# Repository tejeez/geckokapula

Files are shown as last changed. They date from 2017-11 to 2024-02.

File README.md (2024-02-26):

# Gekkokapula
Silicon Labs EFR32 transceivers give access to filtered IQ samples on receive,
so it's possible to make a multimode handheld transceiver using them.

## Features
* Waterfall display (12 kHz wide)
* Receives FM, AM, USB, LSB, CW
* Transmits FM, CW, [USB*](#ssb-transmit), [LSB*](#ssb-transmit)
* Minimalistic user interface with a single knob

## Construction
There are two major versions of the hardware.
The first version is built around a
[BRD4151](https://www.silabs.com/documents/public/reference-manuals/brd4151a-rm.pdf)
radio module and only works in the 2.3-2.9 GHz band.
See [hardware\_v1/](hardware_v1/README.md) for details.

The second version is built on a custom PCB and uses a dual band EFR32 chip.
See [hardware_v2/pcb/](hardware_v2/pcb/) for a KiCad schematic and PCB design.
Construction is documented in [hardware_v2 README file](hardware_v2/README.md).

There is also a [tutorial for flashing firmware](firmware/flashing.md).

## Frequency range for the dual band model
The second version was initially designed for the 70 cm (432 MHz)
and 13 cm (2.3 GHz) amateur radio bands. Later it was found that
the EFR32 can be made to tuner over a much broader range.
Matching circuits of sub-GHz path in current hardware are optimized
for 70 cm but work reasonably well for lower frequencies as well.
Modification for the 23 cm band should be possible but has not
been attempted yet.

Tuning range has some gaps but covers the following frequencies:
* 13.2 - 725 MHz
* 766.7 - 966.6 MHz
* 1.15 - 1.45 GHz
* 2.3 - 2.9 GHz

## SSB transmit

\* SSB is transmitted as a constant envelope signal by only modulating
the frequency of a synthesizer. Amplitude variations are discarded and
the synthesizer is made to approximately track the phase of an SSB
modulated signal. This results is somewhat distorted audio and some
splatter to neighboring channels, but it sounds surprisingly
intelligible and has even received reports of good sound quality.
During quiet moments, some carrier is added in order to have
something to transmit.

Having a slightly dirty spectrum, this SSB transmitting trick
may not be suitable for high transmit power on a crowded bands,
but is probably acceptable for VHF/UHF contacts at low transmit power.

## Licensing

The firmware is released under the [MIT license](firmware/LICENSE).
It depends on the Gecko SDK from Silicon Labs,
mostly licensed under the Zlib license.

I haven't decided on licensing of the hardware design yet.

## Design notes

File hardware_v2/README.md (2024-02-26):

# Hardware version 2.2

## Overview

The Gekkokapula kit currently includes:
* Gekkokapula PCB v2.2
* Display module
* Pin header for display module
* 2 U.FL-SMA cables

To build a complete radio, you will additionally need:
* Enclosure
* Speaker
* Quadrature encoder (may be added to kit in future)
* Electret microphone (may be added to kit in future)
* 1S Li-Ion (or 3S NiMH) battery
* PTT button (optional)
* Volume potentiometer (optional)
* Power switch (optional)
* Serial Wire Debug adapter (to update firmware)

Most of these parts are connected to header J1 on the Gekkokapula PCB.
Schematic diagram of wiring between header J1 and other parts:

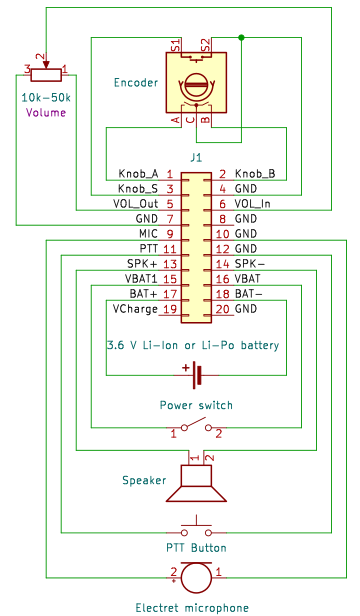
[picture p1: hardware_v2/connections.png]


It is a good idea to connect the battery last after connecting
everything else. This reduces the risk of accidental short circuits
during construction.

## Detailed information

### Gekkokapula board
The Gekkokapula PCB contains most of the electronics.
All SMD components are already placed on the board, so
you only need to hand solder some through hole pin headers.
All bigger and more "mechanical" parts are wired to these
pin headers. This lets you choose any enclosure
you like and arrange all the knobs, buttons and connectors
the way you like.

### Display
Solder 8-pin female header to J9 on Gekkokapula board
and plug display module into the header.

The display is a
[128x160 RGB TFT module with an 8-pin header](https://www.ebay.com/itm/403774302965).

These display modules also include an SD card slot
but it is not used for anything in Gekkokapula.
The 4-pin SD card header J10, however, can be placed and used for
additional mechanical support and ground pins.

### Encoder
The most important part of the user interface is a quadrature
encoder with a push button.
Connect one as shown in the wiring diagram above.

### Speaker
Connect a speaker between SPK+ and SPK- pins
(pins 13 and 14 on header J1).
Almost any speaker should work.
A 4 Ω or 8 Ω speaker with a power handling of at least 1 W
is recommended.

Keep in mind that most speakers need an enclosure to work properly.
A small speaker without an enclosure may sound too quiet.

### Microphone
Connect an electret microphone capsule between MIC and GND
(pins 9 and 10 on header J1).
Most electret microphones should work here.

### Battery
The board includes a protection circuit and a charger for a single
cell Li-Ion or Li-Po battery with a nominal voltage of 3.6 or 3.7 V.
For example, a flat cellphone battery or a 18650 cell can be used.

Connect battery between BAT+ and BAT- pins
(pins 17 and 18 on header J1). Note that battery minus is not
directly connected to ground (because of the protection circuit).

Although designed for Lithium batteries, the circuit also works
with 3 NiMH cells in series, since their voltages are
[close enough](https://www.ti.com/lit/an/slyt468/slyt468.pdf)
to 1S Li-Ion.

### Charging
The battery charger works with any supply voltage from 4 V to 9 V
between VCharge pin and GND (pins 19 and 20 on header J1).

5 V from a USB port or a cellphone charger works fine.

### RF connections
All RF connectors on the board are U.FL. Use pigtail cables
to adapt them to your favourite RF connectors.

13 cm band has its own connector, J3. It is used for
receiving and transmitting in the 2300-2900 MHz range.
All lower frequency bands (13 MHz to 1.45 GHz) use the
connector J5.

J4 is not connected by default but the board can be
[modified to make it an RX connector](#separate-connectors-for-rx-and-tx).

J6 (CLKOUT) is currently unused but may be used in future as a reference
frequency output for transverters.

## Optional parts

### PTT button
A PTT button is optional since transmitting can be also started
from the "menu" using the encoder.

If you prefer to have a dedicated button for PTT, connect one
between PTT and GND (pins 11 and 12 on header J1).

### Power switch
A power switch is optional since there is software and hardware
support for a sleep mode which reduces current consumption
to a few µA.

If you prefer to have a "real" power switch, connect a toggle
switch between PWSW pins (pins 15 and 16 on header J1).

If a switch is not used, connect pins 15 and 16 directly together.

### Volume potentiometer
A volume potentiometer is optional since volume can be also
adjusted from the "menu" using the encoder.

If you prefer to have a dedicated knob for volume, connect
a potentiometer between pins 5, 6 and 7 on header J1
as illustrated on the silkscreen.
Resistance of the potentiometer should be something from
10 kΩ to 50 kΩ.

If a potentiometer is not connected, connect pins 5 and 6
together. Volume can be also reduced by adding a fixed
series resistor or a voltage divider here.

## Bugs
PCB v2.1 has its RF switch control lines swapped.
This can be fixed by moving series resistors
R76 and R77 to cross the lines.
This has been fixed in version 2.2.

Sometimes the board does not power up after battery has been
connected. Seems like the battery protection chip ends up in
some state where it disconnects the battery. If this happens,
try momentarily shorting GND and BAT- together to bypass the
protection circuit. Usually it starts working and keeps working
as long as battery is kept connected.

Silkscreen marking of one expansion header pin in wrong in
both v2.1 and v2.2: pin 2 of J2 is marked as GND but is
actually connected to VBAT.

## Advanced use and modifications

### Updating firmware and debugging
The EFR32 chip on the board is flashed through
Serial Wire Debug (SWD). The board has a 10-pin header with
[Cortex Debug standard pinout](https://documentation-service.arm.com/static/5fce6c49e167456a35b36af1)
but using 2.54 mm pitch instead of the standard 1.27 mm pitch
(to make it easier to solder wires or connectors to it).

GND, SWCLK and SWDIO pins are required and shall be connected to
corresponding pins on your SWD adapter.

The VDD pin is an output meant for SWD adapters with a reference
voltage input (used for level shifters or target detection).
If your SWD adapter does not have a reference voltage input,
leave the VDD pin unconnected. Using this VDD pin to supply power
to the Gekkokapula board is not recommended.

If your SWD adapter has a 5 V output pin, it can be used to supply
power to the board by connecting 5 V to pin 16 on J1
(power switch pin).
If you have a battery connected, you can also connect 5 V
to pin 19 on J1 (VCharge) to charge the battery.

Any SWD adapter supported by OpenOCD should work but may need
additional configuration for OpenOCD.
I can try to add configuration for more adapters
if you can give me an adapter to test with.

See [flashing tutorial](../firmware/flashing.md) for details
on installation and use of flashing software.

### Using without battery
If you want to directly use an external power supply and bypass
battery protection and charging circuits, connect the supply
between power switch VBAT pin (pin 16 on J1) and ground
(such as pin 20 on J1).

The circuit can handle supply voltages from 3 V to 6 V.
Keep in mind that a higher voltage will result in higher power
dissipation in 3.3 V regulator and audio amplifier chips.
Recommended range is between 3.5 V and 5.0 V to keep voltage
regulator working and to keep its dissipation reasonable.

### Headphone connector
Output of the audio power amplifier is bridged, so neither end of
the speaker is connected to ground.

If you want to add a headphone jack, it may be more convenient to
connect one end of headphones to ground, particularly if you use
a 4-pin headset connector with a microphone pin. This can be done
but an additional DC blocking capacitor is needed.
Series resistors are also recommended to protect the audio amplifier
from short circuits.

TODO: diagram showing additional circuitry for a headphone jack

### Use on bands other than 13 cm and 70 cm
The board includes a low-pass filter (LPF) for the 70 cm band.
This is needed to suppress transmitter harmonics and receiver
harmonic mixing products.
RF matching circuits are also optimized for 70 cm but will
work on other bands with somewhat reduced transmit power
and receive sensitivity.

For use on other bands, the LPF should be bypassed
(by moving C82 and R78) and an external LPF should be
connected between J5 and an antenna.
Receiving lower bands without modification or external
filtering is possible but the receiver is prone to harmonic
mixing if a proper LPF is not used. This means you may hear
spurious responses from higher frequencies, such as
FM broadcast signals when trying to listen to HF,
or 70cm band signals when trying to listen to 2m.

### Separate connectors for RX and TX
J4 can be used as a separate receiving connector for frequencies
below 1.45 GHz. This can be useful with an external power amplifier,
low noise amplifier or a transverter.
To use J4, move capacitor C74 to connect receiving chain to J4
through TP5 (and to disconnect it from the RX/TX switch).

On 2300-2900 MHz, J3 is always used for both TX and RX.
Separate connectors for 13 cm are not available.

### Changing charging current
Charge current is limited to approximately 400 mA.
If you want to change the current limit, check the
[data sheet of the charger chip](https://datasheetspdf.com/pdf-file/1090540/NanJingTopPower/TP4054/1)
and change resistor R2 value.

### Expansion header
Header J2 gives access to different supply voltages,
TX/RX switch controls and some free EFR32 pins.
These could be used to control an additional power amplifier
or switched band filters. No such expansions exist at the moment
but they might be developed in the future.

During transmission, TX_EN (pin 19) is high (at 3.3 V) and
RX_EN pin (pin 17) is low (at 0 V).
During reception, TX_EN is low and RX_EN is high.
These pins can be used to control an external power amplifier
and RX/TX switching.

VDD (pin 3) is directly connected to output of a 3.3 V regulator
that powers most of the components on the board.
VDDS (pin 5) is VDD through a power switch that turns off when
the board is in sleep mode. These pins can be used to supply
a few tens of milliamperes for external logic.

DVDD (pin 7) is the output from an EFR32 internal switching
regulator used to supply some parts of the EFR32 chip.
Powering external circuits from this pin is not recommended
since maximum current draw has not been determined yet.

VBAT (pins 1 and 2) are battery voltage output pins.
These can be used to supply an external power amplifier.

PA0, PA1, PB11 and PB12 are free for use by expansion boards.
PB11 and PB12 might be used in future for an I2C bus.
For example, an I2C I/O expander could be used to add more I/O
pins to control a band switch.
PA0 and PA1 were used for an UART in some old firmware versions
but the pins are currently unused.

PA2 is connected on the board for battery voltage measurement
and PA5 for battery charge detection. These features are currently
unimplemented in firmware, so the pins have been brought to the
header to allow using them for other purposes as well.
If you want to use them for something else, remove jumpers
R1 (for PA5) and R13 (for PA2) from the board.

Free EFR32 pins could be even used to interface some external
sensors or a computer, allowing some "IoT" or "modem" kind of
applications. I have no plans for such expansions at the moment
but anything is possible. Feel free to experiment!

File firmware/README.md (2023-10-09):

# Gekkokapula firmware

# Files in the project
The project was originally made in Simplicity Studio.
Simplicity Studio, however, was found difficult to use for development
since a project opened on another machine was usually broken, its
configuration generators regularly broke something in the project,
and it was quite frustrating in general. Now the code can be compiled
with `make`, and Simplicity Studio is only needed to generate the
radio configuration.

*InitDevice.c* and *InitDevice.h* have been generated by
Simplicity Studio long ago based on the *\*.hwconf* file, which may
not open properly on a newer version. Other old generated files
have been removed.

A project for generating the RAIL configuration is in a different
directory, *../railconfig*. The generated files *rail_config.c*
and *rail_config.h* are compiled as a part of the program.

The application code is under src/ and inc/.

Font is from https://github.com/dhepper/font8x8/

# Compiling and flashing
## Using Visual Studio Code
The project includes configuration for
[Visual Studio Code](https://code.visualstudio.com/download)
and the Cortex-Debug extension.
To develop with Visual Studio Code, choose **File -> Open Folder**
and open this firmware directory
(note: not the upper directory of the whole repository).

Install the following VS Code extensions:
* **C/C++** from **Microsoft**
* **Arm toolchain Linux**, **Arm toolchain Windows** or **Arm toolchain macOS**
  (depending on your operating system) from **Chipcode**
* **Cortex-Debug** from **marus25**
* **RTOS Views** from **mcu-debug**

Install OpenOCD. See [flashing tutorial](flashing.md) for details.

To build or flash the firmware, press **Ctrl+Shift+B**.
The build task will ask for the hardware model, SWD adapter type
and whether you want to only build or also flash the firmware.

To use the debugger, press **F5**.
If you have made changes to code, remember to flash the new firmware
before starting debugging.

## Alternative way: using command line tools only (on Linux)
If you have installed the Arm toolchain as an extension for VS Code,
you can also use it from command line by first doing:

    export PATH="${HOME}/.vscode/extensions/chipcode-nl.gcc-arm-linux-1.0.1/bin:$PATH"

If not, install the toolchain first. For example, on Ubuntu:

    # Skip this if you followed VS Code instructions above
    sudo apt install make gcc-arm-none-eabi libnewlib-arm-none-eabi gdb-multiarch openocd

See [flashing tutorial](flashing.md) for details on setting up OpenOCD.

Compiling the firmware:

    make -j4 KAPULA=v2

Compiling and flashing the firmware (replace `jlink` with `stlink` or `cmsis-dap` if needed):

    make -j4 flash KAPULA=v2 SWD_ADAPTER=jlink

Running OpenOCD to use a debugger or to view RTT debug prints:

    export SWD_ADAPTER=jlink
    openocd -f openocd/rtt.cfg

Replace KAPULA=v2 with KAPULA=v1 for the first version built
from 2.4 GHz radio modules. The first version has had some problems
with flashing but try this a couple of times if it does not work
the first time:

    export SWD_ADAPTER=jlink
    openocd -f openocd/flash_v1.cfg

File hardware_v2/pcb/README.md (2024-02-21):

# Circuit and PCB design for hardware version 2.2

The PCB is designed so that all SMD components can be placed by
[JLCPCB](https://jlcpcb.com/).

Tutorials for ordering:
* [How to generate Gerber and Drill files in KiCad 7](https://jlcpcb.com/help/article/362-how-to-generate-gerber-and-drill-files-in-kicad-7)
* [How to generate the BOM and Centroid file from KiCAD](https://jlcpcb.com/help/article/81-How-to-generate-the-BOM-and-Centroid-file-from-KiCAD)

Make sure each component gets placed in the right orientation.
Pin 1 of each IC is marked with a dot on the silkscreen.

## Settings for JLCPCB Standard PCB/PCBA

* PCB Qty: 30
* Surface Finish: LeadFree HASL
* Specify Layer Sequence: Yes, F / In1 / In2 / B
* Impedance Control: Yes, JLC046161H-7628 (Prepreg thickness 0.2104 mm)
* Remove Order Number: Specify a location
* PCB Assembly: Yes
* Tooling holes: Added by Customer

## Component placement corrections

* U.FLs: Rotate right, move 4 steps
* U1: Rotate (forgot how much)
* U4: Rotate right
* U2, U3, U7, Q1, Q2, Q3, Q4, Q5, Q6: Rotate 180°

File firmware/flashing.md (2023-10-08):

# Flashing the firmware

The firmware is flashed using Serial Wire Debug (SWD), a standard interface
of ARM microcontrollers. SWD is like JTAG but needs less pins.
There are lots of different USB-SWD adapters that could be used.

See [hardware documentation](../hardware_v2/README.md#flashing-and-debugging)
for connections between SWD adapter and board.

## Some possible SWD adapters

### J-Link
Some J-Link compatible adapters that could work:
* Genuine J-Link from SEGGER (really expensive). Also works with
  [SEGGER J-Flash](https://gist.github.com/2ftg/d324652f54836944ba25492ce89025fc).
* [A cheap "J-Link" clone](https://www.ebay.com/itm/256009191453).
  These do not work with SEGGER software but work fine with OpenOCD.
* J-Link integrated on a development board such as Silicon Labs WSTK.
  (There is one you can use at OH2TI radio club.)

### ST-Link
* ST-Link integrated on some STM32 Nucleo development board.
  Remove two jumpers that connect SWD to STM32 and use the
  SWD pin header.
  (TODO: Find a clear picture of pinout and connections for these.)
* [A cheap ST-Link clone](https://www.ebay.com/itm/364490903972)
  (search eBay for ST-LINK).
  Not tested but might work too.

### CMSIS-DAP
Adapters using the standard CMSIS-DAP protocol
are available from several manufacturers. Maybe this means that
there are less problems with software refusing to work when they
detect a clone (the problem with J-Link clones).
I have not tested any of these yet but there are some cheap options:
* https://www.aliexpress.com/item/1005004095909283.html :
  Cheap and small enough you could just put it permanently inside
  your radio. It also has a 5 V output pin, so it would work
  as a USB charging port too.
* https://www.aliexpress.com/item/1005003095115792.html
* Many others. If you know a good one, tell me and I can add it
  here in the list.

### SBC GPIO pins
If you do not want to buy any USB adapter but happen to have a
Raspberry Pi or some other Linux single-board computer around,
you could also use its GPIO pins as an SWD adapter.
OpenOCD has
[drivers](https://openocd.org/doc/html/Debug-Adapter-Configuration.html)
*bcm2835gpio* for Raspberry Pi and *linuxgpiod* for any board.

You may have to compile OpenOCD yourself to get support for these,
so it may get difficult if you are not an experienced Linux user.

## Flashing using OpenOCD software
OpenOCD is good in that it supports a lot of different SWD adapters
and can do a lot of things.
Its downside is that it can feel somewhat complicated to use
if you are not familiar with it.
I try to provide straightforward instructions here so you do not need
to learn too much about OpenOCD just to get your firmware flashed.

### Installing on Linux
On Ubuntu, Debian, Mint or similar, do:

    sudo apt install openocd

Your user needs permissions to access SWD adapter hardware.
This can be done using udev rules. Download
https://raw.githubusercontent.com/openocd-org/openocd/master/contrib/60-openocd.rules
and copy it to the right place:

    sudo cp 60-openocd.rules /etc/udev/rules.d/
    sudo udevadm control --reload

Connect your SWD adapter after copying these udev rules.

If it does not work, a common reason is that openocd does not have
permissions to use your SWD adapter, maybe because the udev rule
does not work on your system for some reason.
In this case, you could try adding `sudo ` in front of openocd
commands (which is not good practice though).

### Installing on Windows
[OpenOCD website](https://openocd.org/pages/getting-openocd.html#unofficial-binary-packages)
lists a few places where you can download OpenOCD for Windows.
I do not actively use it on Windows so I cannot give detailed
instructions, but I tested it a few years ago and it worked.
I had to use  [Zadig](https://zadig.akeo.ie/)
to make Windows use the WinUSB driver for my J-Link clone.
I am not sure if that applies to other SWD adapters.

### Installing on Mac and other systems
OpenOCD supports Mac, too, but I do not have any Apple computer to
test with, so I do not know if it needs some extra configuration.

### Flashing
OpenOCD needs to know which SWD adapter you have.
The [openocd/](openocd/) directory here contains an OpenOCD script
with configuration for a few different adapters.
The adapter can be selected by setting a SWD_ADAPTER environment
variable before starting OpenOCD.
To test it, `cd` to this firmware directory and do:

    # Replace with stlink or cmsis-dap if needed
    export SWD_ADAPTER=jlink
    openocd -f openocd/adapter.cfg

To flash a firmware binary, do:

    openocd -f openocd/adapter.cfg -c init -c 'program "path_to_firmware.bin" verify reset' -c exit

Replace path_to_firmware.bin with the filename of your firmware binary.

## Other software options
Some other software you could try if OpenOCD does not work for you:
* [Simplicity Commander](https://community.silabs.com/s/article/simplicity-commander?language=en_US):
  Silicon Labs tool to flash EFR32 chips.
  Last time I installed it was maybe 5 years ago, so I do not have
  up to date knowledge on it. It worked well, but installing SiLabs
  software was complicated.
* SEGGER J-Flash: Only works with genuine SEGGER J-Link adapters.
  See [instructions to flash using J-Flash](https://gist.github.com/2ftg/d324652f54836944ba25492ce89025fc).
* pyOCD: Sort of an alternative to OpenOCD. Might be easier to use,
  work better for some usecases or something, but does not seem to
  support as many SWD adapters as OpenOCD does.

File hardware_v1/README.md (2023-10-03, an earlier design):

# Construction of Gekkokapula v1
BRD4151A radio board (with EFR32MG1P232F256GM48)
is connected to a display and a speaker.

The display is something like this: https://www.ebay.com/itm/232327157750

Speaker is driven from a PWM output through a series capacitor and a resistor.

| Board pin | EFR32 pin | Connection |
|---|---|---|
| GND | | Ground plane |
| VMCU\_IN  | | +3.3 V |
| P1 | PC6 | Display SDA  |
| P3 | PC7 | Display CS |
| P5 | PC8 | Display SCK  |
| P7 | PC9 | Display AO |
| P12 | PC10 | Display LED  |
| P9 | PA0 | Debug UART TX (currently not used) |
| P11 | PA1 | Debug UART RX (currently not used) |
| P34 | PF6 | PTT or CW key (switch to GND) (optional) |
| P4 | PD10 | PWM Audio out |
| P6 | PD11 | Encoder A (switch to GND) |
| P8 | PD12 | Encoder B (switch to GND) |
| P31/F18 | PD13 | Encoder push button (switch to GND) |
| F14 | PD15 | Audio in, biased around 0.625 V |
| P24 | PF0 | J-link SWCLK |
| P26 | PF1 | J-link SWDIO |

VCC and RESET pins on display are connected to +3.3 V.

If you push wires straight to the radio board headers, reading pinout from the
datasheet is prone to mistakes as you are looking at it mirrored.
Here's a mirrored pinout to help:
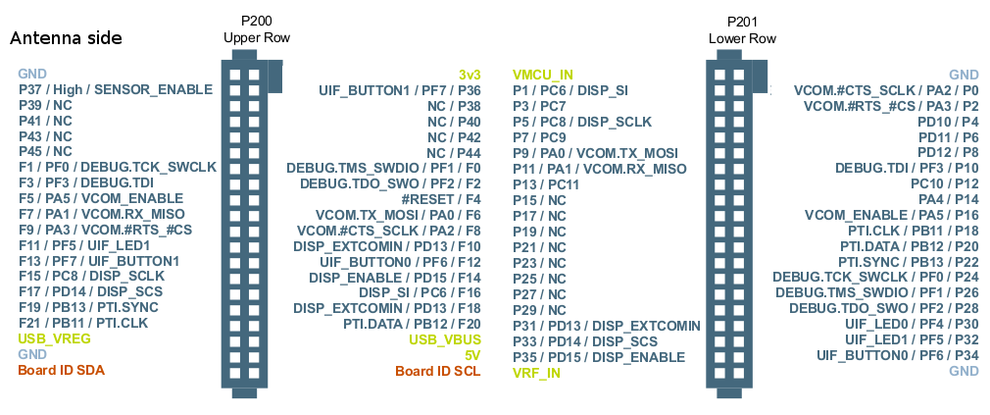
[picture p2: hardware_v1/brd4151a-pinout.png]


## Flashing
See [flashing tutorial](../firmware/flashing.md).
Should I just add compiled firmware binaries here in the repository?

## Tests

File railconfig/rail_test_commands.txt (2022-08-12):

// Copyright 2022 Silicon Laboratories, Inc.
//
//

rx 0
writeRmrStructure 0 0 8 5 0 0 0 232 180 1 0
writeRmrStructure 0 20 8 0 0 0 0 128 7 155 0
writeRmrStructure 0 28 8 0 240 73 2 128 62 0 0
writeRmrStructure 0 36 8 1 1 0 0 0 8 0 2
updateConfigurationPointer 0 2 255
updateConfigurationPointer 0 3 1
updateConfigurationPointer 0 4 255
writeRmrStructure 1 0 1 25
writeRmrStructure 1 1 8 63 1 6 4 16 1 0 0
writeRmrStructure 1 9 8 1 1 6 0 16 39 0 0
writeRmrStructure 1 17 8 5 0 1 1 0 0 0 0
writeRmrStructure 1 25 1 0
writeRmrStructure 2 0 8 240 15 4 1 0 0 0 0
writeRmrStructure 2 8 8 0 0 0 0 2 192 3 0
writeRmrStructure 2 16 8 0 192 3 0 4 0 2 0
writeRmrStructure 2 24 8 0 0 0 0 0 0 0 0
writeRmrStructure 2 32 8 24 0 2 0 15 0 0 0
writeRmrStructure 2 40 8 0 0 0 0 40 0 7 0
writeRmrStructure 2 48 8 0 0 0 0 0 0 0 0
writeRmrStructure 2 56 8 0 0 0 0 0 0 0 0
writeRmrStructure 2 64 8 0 0 0 0 0 0 0 0
writeRmrStructure 2 72 8 0 7 0 0 72 0 1 0
writeRmrStructure 2 80 8 0 0 0 0 84 0 2 0
writeRmrStructure 2 88 8 0 0 0 0 0 0 0 0
writeRmrStructure 2 96 8 160 0 4 0 255 64 0 0
writeRmrStructure 2 104 8 0 0 0 0 255 65 0 0
writeRmrStructure 2 112 8 0 0 0 0 0 32 1 0
writeRmrStructure 2 120 8 0 7 0 0 16 32 1 0
writeRmrStructure 2 128 8 0 0 0 0 24 32 1 0
writeRmrStructure 2 136 8 0 0 0 0 8 48 1 0
writeRmrStructure 2 144 8 63 172 0 0 48 48 2 0
writeRmrStructure 2 152 8 0 8 16 0 1 0 0 0
writeRmrStructure 2 160 8 64 48 1 0 0 0 0 0
writeRmrStructure 2 168 8 160 64 1 0 122 39 0 15
writeRmrStructure 2 176 8 244 64 1 0 32 16 0 0
writeRmrStructure 2 184 8 52 65 2 0 128 8 0 0
writeRmrStructure 2 192 8 230 135 0 0 64 65 2 0
writeRmrStructure 2 200 8 32 0 136 0 193 230 83 17
writeRmrStructure 2 208 8 20 96 21 0 16 0 0 0
writeRmrStructure 2 216 8 0 0 0 4 1 0 2 0
writeRmrStructure 2 224 8 0 16 0 0 0 208 10 0
writeRmrStructure 2 232 8 0 0 0 3 0 0 0 0
writeRmrStructure 2 240 8 188 127 109 0 65 4 0 0
writeRmrStructure 2 248 8 28 3 0 2 18 0 1 0
writeRmrStructure 2 256 8 2 0 0 0 0 0 0 0
writeRmrStructure 2 264 8 3 0 108 4 0 0 0 0
writeRmrStructure 2 272 8 21 3 52 0 0 0 0 0
writeRmrStructure 2 280 8 0 0 0 0 4 10 20 34
writeRmrStructure 2 288 8 51 65 75 80 0 0 0 0
writeRmrStructure 2 296 8 20 112 3 0 254 112 2 0
writeRmrStructure 2 304 8 0 19 0 0 96 0 113 129
writeRmrStructure 2 312 8 40 112 1 0 0 0 128 1
writeRmrStructure 2 320 8 72 112 2 0 60 61 0 0
writeRmrStructure 2 328 8 188 25 0 0 112 112 3 0
writeRmrStructure 2 336 8 3 1 2 0 18 1 0 0
writeRmrStructure 2 344 8 0 35 85 0 255 255 255 255
writeRmrStructure 6 0 4 255 255 255 255
writeRmrStructure 7 4 8 0 24 13 143 100 0 0 0
writeRmrStructure 7 12 8 0 0 0 0 20 0 255 127
updateConfigurationPointer 2 1 0
reconfigureModem
getRadioState

//        _  _                          
//       | )/ )         Wireless        
//    \\ |//,' __       Application     
//    (")(_)-"()))=-    Software        
//       (\\            Platform

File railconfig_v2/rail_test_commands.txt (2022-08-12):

// Copyright 2022 Silicon Laboratories, Inc.
//
//

rx 0
writeRmrStructure 0 0 8 5 0 0 0 81 184 30 0
writeRmrStructure 0 20 8 0 0 0 0 0 207 153 0
writeRmrStructure 0 28 8 0 240 73 2 128 62 0 0
writeRmrStructure 0 36 8 1 1 0 0 0 144 0 36
updateConfigurationPointer 0 2 255
updateConfigurationPointer 0 3 1
updateConfigurationPointer 0 4 255
writeRmrStructure 1 0 1 25
writeRmrStructure 1 1 8 67 18 6 4 16 0 1 1
writeRmrStructure 1 9 8 2 1 6 0 16 39 0 0
writeRmrStructure 1 17 8 5 0 1 1 0 0 0 0
writeRmrStructure 1 25 1 0
writeRmrStructure 2 0 8 240 31 4 1 63 0 63 0
writeRmrStructure 2 8 8 0 0 0 0 0 0 0 0
writeRmrStructure 2 16 8 0 0 0 0 4 0 2 0
writeRmrStructure 2 24 8 0 0 0 0 0 0 0 0
writeRmrStructure 2 32 8 24 0 2 0 15 0 0 0
writeRmrStructure 2 40 8 0 0 0 0 40 0 7 0
writeRmrStructure 2 48 8 0 0 0 0 0 0 0 0
writeRmrStructure 2 56 8 0 0 0 0 0 0 0 0
writeRmrStructure 2 64 8 0 0 0 0 0 0 0 0
writeRmrStructure 2 72 8 0 7 0 0 72 0 1 0
writeRmrStructure 2 80 8 0 0 0 0 84 0 2 0
writeRmrStructure 2 88 8 0 0 0 0 0 0 0 0
writeRmrStructure 2 96 8 160 0 4 0 255 64 0 0
writeRmrStructure 2 104 8 0 0 0 0 255 65 0 0
writeRmrStructure 2 112 8 0 0 0 0 0 32 1 0
writeRmrStructure 2 120 8 0 7 0 0 16 32 1 0
writeRmrStructure 2 128 8 0 0 0 0 24 32 1 0
writeRmrStructure 2 136 8 0 0 0 0 8 48 1 0
writeRmrStructure 2 144 8 19 172 0 1 48 48 2 0
writeRmrStructure 2 152 8 0 144 16 0 155 0 0 0
writeRmrStructure 2 160 8 64 48 1 0 0 0 0 0
writeRmrStructure 2 168 8 160 64 1 0 170 39 0 15
writeRmrStructure 2 176 8 184 64 1 0 0 192 35 0
writeRmrStructure 2 184 8 244 64 1 0 32 16 0 0
writeRmrStructure 2 192 8 52 65 2 0 128 8 0 0
writeRmrStructure 2 200 8 246 135 0 0 64 65 2 0
writeRmrStructure 2 208 8 32 0 136 0 193 230 82 77
writeRmrStructure 2 216 8 96 65 4 0 0 0 0 0
writeRmrStructure 2 224 8 0 0 0 0 6 0 0 0
writeRmrStructure 2 232 8 6 0 0 0 20 96 8 0
writeRmrStructure 2 240 8 16 0 0 0 0 0 0 4
writeRmrStructure 2 248 8 1 0 2 0 0 16 0 0
writeRmrStructure 2 256 8 0 208 10 0 0 0 0 3
writeRmrStructure 2 264 8 0 0 0 0 0 0 0 0
writeRmrStructure 2 272 8 80 96 6 0 188 127 109 0
writeRmrStructure 2 280 8 65 4 0 0 28 3 0 0
writeRmrStructure 2 288 8 18 0 1 0 2 0 0 0
writeRmrStructure 2 296 8 0 0 0 0 120 96 12 0
writeRmrStructure 2 304 8 3 0 108 4 0 0 0 0
writeRmrStructure 2 312 8 151 3 52 0 0 0 0 0
writeRmrStructure 2 320 8 0 0 0 0 4 10 20 34
writeRmrStructure 2 328 8 50 65 74 79 0 0 0 0
writeRmrStructure 2 336 8 0 0 0 0 0 0 0 0
writeRmrStructure 2 344 8 0 0 0 0 0 0 0 0
writeRmrStructure 2 352 8 228 96 7 0 128 0 0 132
writeRmrStructure 2 360 8 0 0 0 0 100 4 131 7
writeRmrStructure 2 368 8 136 19 200 58 144 32 10 0
writeRmrStructure 2 376 8 0 97 32 0 183 86 53 18
writeRmrStructure 2 384 8 4 97 3 0 0 128 16 0
writeRmrStructure 2 392 8 32 48 4 41 136 187 64 0
writeRmrStructure 2 400 8 32 97 1 0 0 0 0 0
writeRmrStructure 2 408 8 40 97 1 0 100 6 102 12
writeRmrStructure 2 416 8 48 97 12 0 232 83 250 0
writeRmrStructure 2 424 8 0 0 0 0 0 0 0 0
writeRmrStructure 2 432 8 0 0 0 0 0 0 0 0
writeRmrStructure 2 440 8 0 0 0 0 0 0 0 0
writeRmrStructure 2 448 8 1 0 0 0 0 0 0 0
writeRmrStructure 2 456 8 0 0 0 0 0 0 0 0
writeRmrStructure 2 464 8 0 0 0 0 20 112 7 0
writeRmrStructure 2 472 8 254 112 2 0 0 19 0 0
writeRmrStructure 2 480 8 96 0 234 130 0 0 0 0
writeRmrStructure 2 488 8 130 0 0 0 0 0 0 0
writeRmrStructure 2 496 8 213 0 0 0 72 112 2 0
writeRmrStructure 2 504 8 62 56 0 0 188 37 0 0
writeRmrStructure 2 512 8 112 112 3 0 3 1 18 0
writeRmrStructure 2 520 8 67 48 8 0 128 132 109 0
writeRmrStructure 2 528 4 255 255 255 255
writeRmrStructure 6 0 4 255 255 255 255
writeRmrStructure 7 4 8 64 134 164 8 100 0 0 0
writeRmrStructure 7 12 8 0 0 0 0 20 0 255 127
updateConfigurationPointer 2 3 0
reconfigureModem
getRadioState

//        _  _                          
//       | )/ )         Wireless        
//    \\ |//,' __       Application     
//    (")(_)-"()))=-    Software        
//       (\\            Platform

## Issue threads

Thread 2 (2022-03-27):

Reserve a pin for clock output

tejeez, 2022-03-27:
Some users might like to have a frequency divided reference clock available on some pin. The clock management unit (CMU) can output HFEXPCLK on CMU_CLK0 and CMU_CLK1. There's "CMU_HFEXPPRESC - High Frequency Export Clock Prescaler Register" with 5 bits, allowing division factors from 1 to 32.

CMU_CLK0 can be routed to PA1, PB15, PC6, PC11, PD9, PD14, PF2, PF7.
CMU_CLK1 can be routed to PA0, PB14, PC7, PC10, PD10, PD15, PF3 and PF6.
Out of these, the following pins exist on the EFR32FG14P233F256GM48:
* PA0, PA1 - reserved for UART, but not actually used at the moment
* PB14 - used (SPK_PWM)
* PB15 - used (VBAT_ADC)
* PC6, PC7, PC10, PC11 - used for display since version 1, so I'd rather not change these
* PD14, PF7 - used for buttons since they support EM4 wakeup. EM4 is not used for now but could be.
* PD15 - used (RX_EN)
* PF2, PF3 - reserved for SWO and JTAG
* PF6 - used (encoder)

So, which one should we use? Looks like PB14, PB15, PD15, PF6 could be moved somewhere else. That would need modifications to the existing prototypes but I think only 3 of those exist at the moment, so it wouldn't be that bad.

PF3 is "free" and available on a test pad. Does someone want to use JTAG, though?

PA0 and PA1 are already available on a header but the plan was to use that one for UART. UART could be routed to any other free pin, though.

tejeez, 2022-08-07:
PB15 might be a good choice. VBAT_ADC is not even used by the firmware yet, so it could be moved to another pin without breaking anything.

tejeez, 2022-08-29:
Actually, I think PB14 and PB15 are better reserved for an LF crystal.

PF3 is fine. It can be still used for JTAG if someone really wants to.

tejeez, 2023-09-28:
> Actually, I think PB14 and PB15 are better reserved for an LF crystal.
>
> PF3 is fine. It can be still used for JTAG if someone really wants to.

Done.

Closed 2023-09-28.

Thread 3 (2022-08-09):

Ideas for v2.1

tejeez, 2022-08-09:
Let's collect some ideas for the next batch of PCBs here.

I'd rather not maintain a separate firmware for v2 and v2.1, so it should be mostly pinout compatible with v2. If something is changed in the pinout, the existing v2 boards can be modified to work with latest firmware.

I decided to not focus that much on mechanical design yet, so I think v2.1 will just use the same enclosure and similar construction as v2.

List of some ideas:
* Fix enclosure mounting hole positions.
* Remove the BJT microphone preamplifier and try using the internal opamp in EFR32. This would reduce component count and allow adjusting microphone gain from the firmware. This should be tested first by modifying v2 boards.
* Should we still use [ETC4-1-2](https://www.partco.fi/fi/tarjouseraet/3741-tarmuu-etc4-1-2.html) as the balun for EFR32 matching or find a replacement from JLCPCB?
* The class D audio output stage does not have proper filtering. I thought voice coil inductance of a speaker might be enough but haven't actually measured it. Some people, however, have added a headphone connector. How bad is it to continuously feed a ≈1 V 192 kHz tone to headphones?
* https://github.com/tejeez/geckokapula/issues/2
* Make unfiltered RF signals easier to access. EFR32 can tune wider than expected so it would be nice to allow some experimentation. Maybe add some 0-ohm jumpers to bypass filters.
* How about replacing the 3.3 V LDO with a switching regulator for better battery life and less heat? The regulated voltage could be also reduced a bit (say, 3.0 V), so that it maintains regulation even with a bit less battery voltage.

tejeez, 2022-08-09:
This could work as the balun: https://jlcpcb.com/partdetail/MurataElectronics-DXP18BN5014TL/C152552

tejeez, 2023-09-28:
>     * Fix enclosure mounting hole positions.
I decided to not design v2.1 for any specific enclosure, so this is not an issue anymore.
>
>     * Remove the BJT microphone preamplifier and try using the internal opamp in EFR32. This would reduce component count and allow adjusting microphone gain from the firmware. This should be tested first by modifying v2 boards.
This is now done.
>
>     * Should we still use [ETC4-1-2](https://www.partco.fi/fi/tarjouseraet/3741-tarmuu-etc4-1-2.html) as the balun for EFR32 matching or find a replacement from JLCPCB?
Balun are BW21S7511A01TF now.
>
>     * The class D audio output stage does not have proper filtering. I thought voice coil inductance of a speaker might be enough but haven't actually measured it. Some people, however, have added a headphone connector. How bad is it to continuously feed a ≈1 V 192 kHz tone to headphones?
I decided to use a class AB amplifier driven from a DAC instead.
>
>     * [Reserve a pin for clock output #2](https://github.com/tejeez/geckokapula/issues/2)
Done
>
>     * Make unfiltered RF signals easier to access. EFR32 can tune wider than expected so it would be nice to allow some experimentation. Maybe add some 0-ohm jumpers to bypass filters.
Done
>
>     * How about replacing the 3.3 V LDO with a switching regulator for better battery life and less heat? The regulated voltage could be also reduced a bit (say, 3.0 V), so that it maintains regulation even with a bit less battery voltage.
Now that audio amplifier is powered directly from battery voltage, consumption from 3.3 V is not that much. I kept a simple 3.3 V LDO there. EFR32 DAC has its own internal reference too, so even if 3.3 V line stops being regulated when battery goes below 3.3 V, it should not affect audio that much.

Closed 2023-09-28.

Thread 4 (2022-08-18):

OpenRTX support

silseva, 2022-08-18:
Hi!
I'm one of the founders and developers of the OpenRTX project (https://openrtx.org/) and I just found this project: it looks like a perfect match for our work, are you interested in a cooperation?

73,
Silvano IU2KWO.

tejeez, 2022-08-29:
Maybe! I'll take a look at OpenRTX and think about it.

What would you like to do? Port the OpenRTX firmware to the Gekkokapula hardware, replacing my firmware? That sounds doable, though I'm afraid I might not really have enough time, interest and motivation to contribute that much.

To be honest, I sort of like my current firmware the way it is. It has been a fun little hobby side project I don't want to take too seriously. The purpose has been more about learning embedded programming and exploring the capabilities of EFR32 chips rather than trying to implement any certain specified set of features. I never really thought about developing it more seriously as a bigger team, and I already have some other software projects I'm more focused on, so my contributions might be quite limited.

But, if you'd like to start implementing OpenRTX for EFR32 to run it on Gekkokapula-like hardware, go ahead! We can certainly share ideas, experiences and pieces of code. I think EFR32 chips have a lot of potential for this kind of use, and maybe something OpenRTX-based could eventually become a better choice of firmware for a broader range of users.

Another thing where I might be interested in cooperation is the hardware design. So far it has been quite experimental and only a few of these have been built. I've thought it would be cool to turn it into some kind of a kit that could be built by more people, but would really need some help to make it happen. I'm currently designing a PCB for hardware version 2.1 and planning to order a batch of them to share with some local hams. I suppose there could be much more people interested in building one if we could figure out how to make the hardware more widely accessible.

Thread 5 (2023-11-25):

Question.

Skorpionm, 2023-11-25:
Good afternoon, your project is very interesting for me, I’m trying to do something similar, but on the Efr32XG28 it seems to be more powerful and the processor is faster.  can you answer a few questions?  1. Is your firmware suitable for Efr32XG28?  2. how did you defeat resetting the frequency in a wide range, without reloading the configuration for different frequencies.  which configurator do you use, silabs studio does not allow you to set the "actual sample frequency" parameter and my DMA works at the maximum frequency and the processor choke

tejeez, 2023-11-26:
Radio configuration is generated using some old version Simplicity Studio. It indeed did not let me specify a sample rate directly but it wrote a log file containing the sample rate. I adjusted channel bandwidth by trial and error until I got a configuration with the desired sample rate.

A radio configuration indeed has a limited tuning range. I found the main reason is that the frequency synthesizer in EFR32 produces a frequency in 2.3-2.9 GHz range which then goes to frequency divider chain for sub-GHz bands. This division ratio is a part of the radio configuration. The configuration table seems to directly contain values for several registers of the radio peripheral, including the one configuring the frequency divider chain.

When changing frequency, my code modifies the frequency divider field in radio configuration before calling RAIL_ConfigChannels. The radio part is not publicly documented but I found just enough information about the frequency synthesizer in some public code from Silabs:
https://github.com/SiliconLabs/gecko_sdk/blob/310814a9016b60a8012d50c62cc168a783ac102b/platform/radio/efr32_multiphy_configurator/pyradioconfig/parts/common/calculat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

I also found a listing of frequency synthesizer register names:
https://github.com/SiliconLabs/gecko_sdk/blob/310814a9016b60a8012d50c62cc168a783ac102b/platform/radio/efr32_multiphy_configurator/pyradioconfig/to_be_deprecated/cmsi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

And some register field names and positions:
https://github.com/SiliconLabs/gecko_sdk/blob/310814a9016b60a8012d50c62cc168a783ac102b/platform/radio/efr32_multiphy_configurator/host_py_rm_studio_internal/full/efr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

Here is the part of my code doing this:
https://github.com/tejeez/geckokapula/blob/812966eedfe9c394a8de9c38d98c837f25eb3ae3/firmware/src/railtask.c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

I have not tried those EFR32 series 2 chips and seems like their radio part is quite different from series 1. I'm afraid these tricks would not work the same way on series 2, so I have decided to stick to series 1 even though they have a slower processor core.

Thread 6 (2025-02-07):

RX IQ bandwith

fei666888, 2025-02-07:
I would like to know what is the maximum receive bandwidth that can be obtained through the IQ data output. Is it only 12k? I want to get a wider waterfall chart. Is it possible?

tejeez, 2025-03-09:
EFR32 can do a much higher receive bandwidth but it will result in a higher sample rate for the I/Q stream. Bandwidth and sample rate are determined by the [radio configuration table](https://github.com/tejeez/geckokapula/blob/ac5d14fec401f9cc5fbd87fb36ef1e342bc5b2c9/railconfig/rail_config.c) generated in Simplicity Studio. When I generated the configuration table, I adjusted the configured channel bandwidth by trial and error until it resulted in a configuration with a 48 kHz sample rate (as shown in the [radio configurator log file](https://github.com/tejeez/geckokapula/blob/ac5d14fec401f9cc5fbd87fb36ef1e342bc5b2c9/railconfig/efr32_radio_configurator_log.txt)). Resulting sample rate seems to be around 4 times the channel bandwidth configured. Since details of the radio peripheral and configuration table are not really publicly documented, I do not really know if it would be possible to reduce the oversampling factor so that bandwidth could be increased without increasing sample rate that much.

If sample rate is increased, more processing power will be needed to handle the I/Q data. The 38.4 MHz Cortex-M4F processor core is not that fast after all. In the current firmware, there is some spare processor time left but not a lot. It might be possible to make it a bit wider if needed. Everything in the firmware, however, is pretty much hard coded for the 48 kHz sample rate, so you might need several changes around the code to make everything work correctly.

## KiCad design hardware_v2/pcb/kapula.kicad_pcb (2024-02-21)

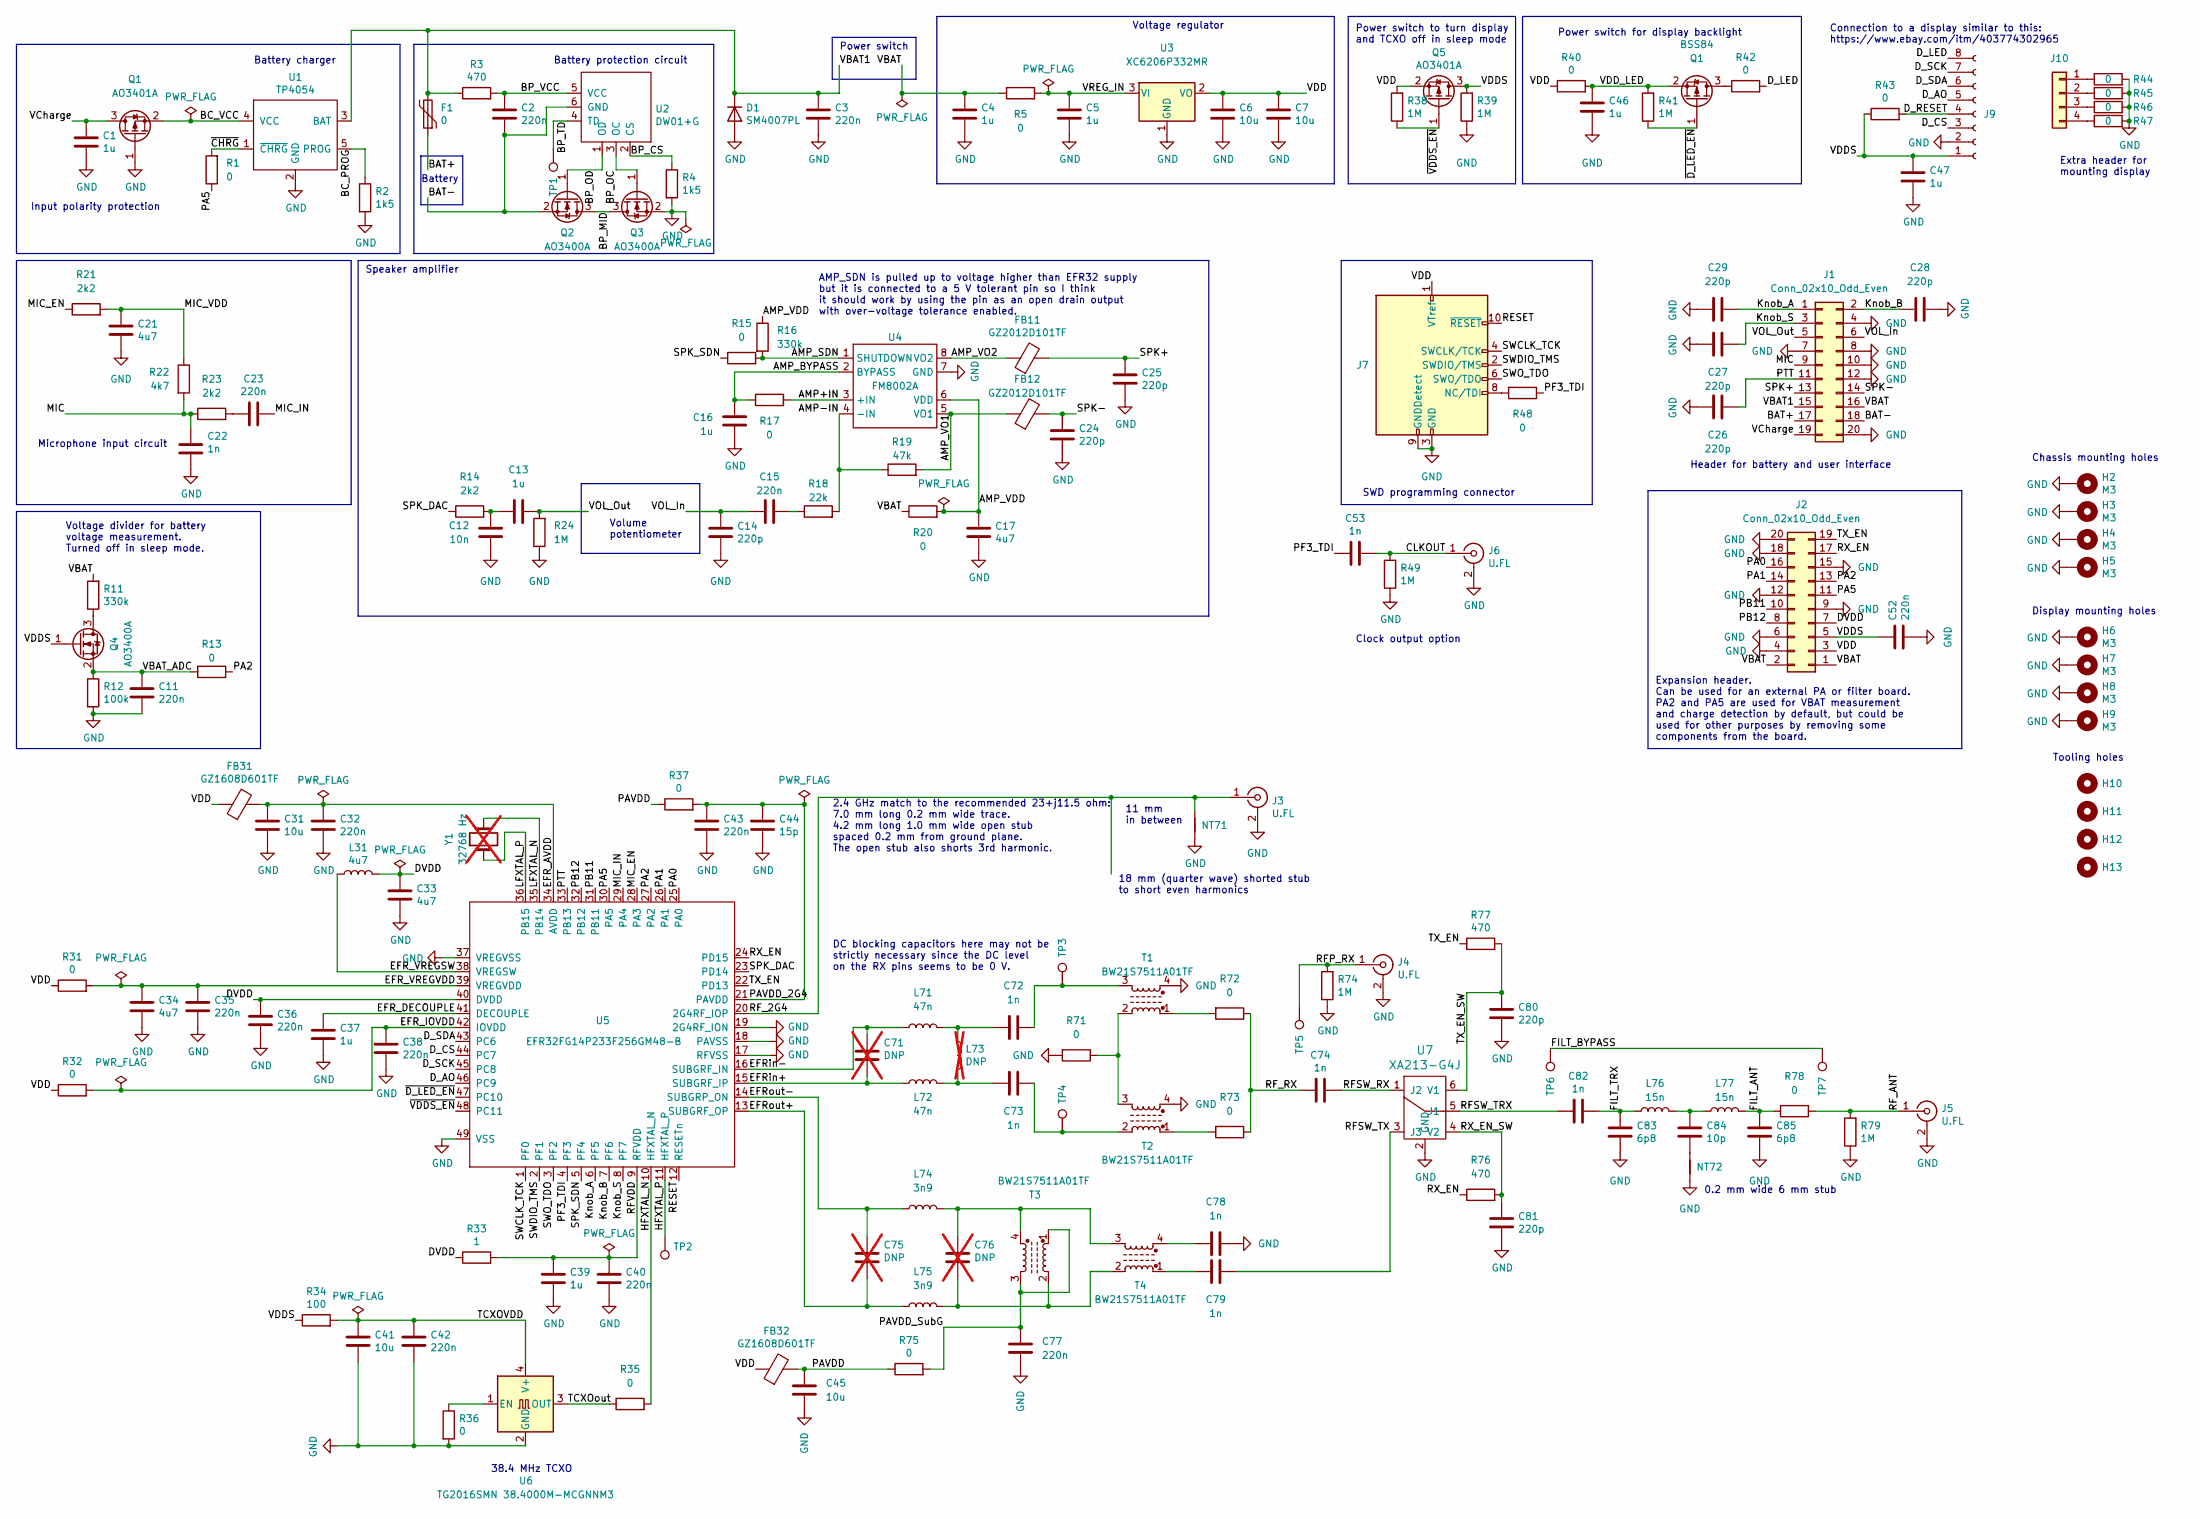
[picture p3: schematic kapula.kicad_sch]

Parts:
C1, C4, C5, C13, C16, C37, C39, C46, C47: 1u; C_0603_1608Metric; LCSC C15849
C2, C3, C11, C23, C32, C35, C36, C38, C40, C42, C43, C52, C77: 220n; C_0402_1005Metric; LCSC C16772
C6, C7, C31, C41, C45: 10u; C_0805_2012Metric; LCSC C15850
C12: 10n; C_0402_1005Metric; LCSC C15195
C14, C24, C25, C26, C27, C28, C29, C80, C81: 220p; C_0402_1005Metric; LCSC C1530
C15: 220n; C_0402_1005Metric_Pad0.74x0.62mm_HandSolder; LCSC C16772
C17, C21, C33, C34: 4u7; C_0805_2012Metric; LCSC C1779
C22, C53, C72, C73, C78, C79: 1n; C_0402_1005Metric; LCSC C1523
C44: 15p; C_0402_1005Metric; LCSC C1548
C71: DNP; C_0402_1005Metric; not fitted
C74, C82: 1n; C_0603_1608Metric_Pad1.08x0.95mm_HandSolder; LCSC C1588
C75, C76: DNP; C_0402_1005Metric_Pad0.74x0.62mm_HandSolder; not fitted
C83, C85: 6p8; C_0603_1608Metric_Pad1.08x0.95mm_HandSolder; LCSC C1679
C84: 10p; C_0603_1608Metric_Pad1.08x0.95mm_HandSolder; LCSC C1634
D1: SM4007PL; D_SOD-123F; LCSC C64898
F1: 0; R_1206_3216Metric_Pad1.30x1.75mm_HandSolder; LCSC C17888
FB11, FB12: GZ2012D101TF; L_0805_2012Metric_Pad1.05x1.20mm_HandSolder; LCSC C1015
FB31, FB32: GZ1608D601TF; L_0603_1608Metric_Pad1.05x0.95mm_HandSolder; LCSC C1002
H2, H3, H4, H5, H6, H7, H8, H9: M3; MountingHole_3.2mm_M3_Pad
H10, H11, H12, H13: ToolingHole
J1, J2: Conn_02x10_Odd_Even; PinHeader_2x10_P2.54mm_Vertical
J3, J4, J5, J6: U.FL; U.FL_Hirose_U.FL-R-SMT-1_Vertical; LCSC C88374
J7: PinHeader_2x05_P2.54mm_Vertical
J9: PinSocket_1x08_P2.54mm_Vertical
J10: PinSocket_1x04_P2.54mm_Vertical
L31: 4u7; L_1206_3216Metric; LCSC C1049
L71, L72: 47n; L_0402_1005Metric_Pad0.77x0.64mm_HandSolder; LCSC C27151
L73: DNP; L_0402_to_0603_HandSolder; not fitted
L74, L75: 3n9; L_0402_1005Metric_Pad0.77x0.64mm_HandSolder; LCSC C14033
L76, L77: 15n; L_0402_1005Metric_Pad0.77x0.64mm_HandSolder; LCSC C27143
NT71: NetTie-2_SMD_Pad0.3mm
NT72: NetTie-2_SMD_Pad0.2mm
Q1, Q5: AO3401A; SOT-23; LCSC C15127
Q2, Q3, Q4: AO3400A; SOT-23; LCSC C20917
R1, R5, R13, R35, R44, R45, R46, R47, R48, R78: 0; R_0603_1608Metric_Pad0.98x0.95mm_HandSolder; LCSC C21189
R2: 1k5; R_0603_1608Metric_Pad0.98x0.95mm_HandSolder; LCSC C22843
R3, R76, R77: 470; R_0402_1005Metric; LCSC C25117
R4: 1k5; R_0603_1608Metric; LCSC C22843
R11: 330k; R_0402_1005Metric_Pad0.72x0.64mm_HandSolder; LCSC C25778
R12: 100k; R_0402_1005Metric_Pad0.72x0.64mm_HandSolder; LCSC C25741
R14, R21, R23: 2k2; R_0402_1005Metric; LCSC C25879
R15, R17, R20, R31, R32, R36, R37, R40, R42, R43, R71, R72, R73, R75: 0; R_0402_1005Metric; LCSC C17168
R16: 330k; R_0402_1005Metric; LCSC C25778
R18: 22k; R_0603_1608Metric_Pad0.98x0.95mm_HandSolder; LCSC C31850
R19: 47k; R_0603_1608Metric_Pad0.98x0.95mm_HandSolder; LCSC C25819
R22: 4k7; R_0402_1005Metric; LCSC C25900
R24, R38, R39, R41, R49, R74, R79: 1M; R_0402_1005Metric; LCSC C26083
R33: 1; R_0603_1608Metric_Pad0.98x0.95mm_HandSolder; LCSC C22936
R34: 100; R_0603_1608Metric_Pad0.98x0.95mm_HandSolder; LCSC C22775
T1, T2, T3, T4: BW21S7511A01TF; BW21S; LCSC C138776
TP1, TP2, TP5, TP6, TP7: Pad_1mm
TP3, TP4: Pad_0402_1005Metric
U1: TP4054; SOT-23-5_HandSoldering; LCSC C32574
U2: DW01+G; SOT-23-6_Handsoldering; LCSC C14213
U3: XC6206P332MR; SOT-23; LCSC C5446
U4: FM8002A; SOP-8_3.9x4.9mm_P1.27mm; LCSC C94625
U5: EFR32FG14P233F256GM48-B; QFN-48-1EP_7x7mm_P0.5mm_EP5.3x5.3mm
U6: TG2016SMN 38.4000M-MCGNNM3; TG2016SMN; LCSC C1987359
U7: XA213-G4J; SOT-363_SC-70-6; LCSC C556294
Y1: 32768 Hz; Crystal_SMD_3215-2Pin_3.2x1.5mm; not fitted

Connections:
/AMP+IN: R17.2, U4.3 (+IN)
/AMP-IN: R18.2, R19.1, U4.4 (-IN)
/AMP_BYPASS: C16.1, R17.1, U4.2 (BYPASS)
/AMP_SDN: R15.2, R16.2, U4.1 (SHUTDOWN)
/AMP_VDD: C17.1, R16.1, R20.2, U4.6 (VDD)
/AMP_VO1: FB12.1, R19.2, U4.5 (VO1)
/AMP_VO2: FB11.1, U4.8 (VO2)
/BAT+: F1.1, J1.17
/BAT-: C2.2, J1.18, Q2.2 (S), U2.6 (GND)
/BC_PROG: R2.1, U1.5 (PROG)
/BP_CS: R4.1, U2.2 (CS)
/BP_MID: Q2.3 (D), Q3.3 (D)
/BP_OC: Q3.1 (G), U2.3 (OC)
/BP_OD: Q2.1 (G), U2.1 (OD)
/BP_TD: TP1.1, U2.4 (TD)
/BP_VCC: C2.1, R3.2, U2.5 (VCC)
/CLKOUT: C53.2, J6.1 (In), R49.2
/DVDD: C33.1, C36.1, J2.7, L31.2, R33.1, U5.40 (DVDD)
/D_AO: J9.5, U5.46 (PC9)
/D_CS: J9.3, U5.44 (PC7)
/D_LED: J9.8, R42.2
/D_RESET: J9.4, R43.2
/D_SCK: J9.7, U5.45 (PC8)
/D_SDA: J9.6, U5.43 (PC6)
/EFR_AVDD: C31.1, C32.1, FB31.2, U5.34 (AVDD)
/EFR_DECOUPLE: C37.1, U5.41 (DECOUPLE)
/EFR_IOVDD: C38.1, R32.2, U5.42 (IOVDD)
/EFR_VREGSW: L31.1, U5.38 (VREGSW)
/EFR_VREGVDD: C34.1, C35.1, R31.2, U5.39 (VREGVDD)
/EFRin+: C71.2, L72.1, U5.15 (SUBGRF_IP)
/EFRin-: C71.1, L71.1, U5.16 (SUBGRF_IN)
/EFRout+: C75.2, L75.2, U5.13 (SUBGRF_OP)
/EFRout-: C75.1, L74.2, U5.14 (SUBGRP_ON)
/FILT_ANT: C85.1, L77.2, R78.2
/FILT_BYPASS: TP6.1, TP7.1
/FILT_TRX: C82.1, C83.1, L76.1
/HFXTAL_N: R35.2, U5.10 (HFXTAL_N)
/HFXTAL_P: TP2.1, U5.11 (HFXTAL_P)
/Knob_A: C29.1, J1.1, U5.6 (PF5)
/Knob_B: C28.1, J1.2, U5.7 (PF6)
/Knob_S: C27.1, J1.3, U5.8 (PF7)
/LFXTAL_N: U5.35 (PB14), Y1.2
/LFXTAL_P: U5.36 (PB15), Y1.1
/MIC: C22.1, J1.9, R22.2, R23.1
/MIC_EN: R21.1, U5.28 (PA3)
/MIC_IN: C23.1, U5.29 (PA4)
/MIC_VDD: C21.1, R21.2, R22.1
/PA0: J2.16, U5.25 (PA0)
/PA1: J2.14, U5.26 (PA1)
/PA2: J2.13, R13.1, U5.27 (PA2)
/PA5: J2.11, R1.1, U5.30 (PA5)
/PAVDD: C45.1, FB32.2, R37.1, R75.1
/PAVDD_2G4: C43.1, C44.1, R37.2, U5.21 (PAVDD)
/PAVDD_SubG: C77.1, R75.2, T3.1, T3.3
/PB11: J2.10, U5.31 (PB11)
/PB12: J2.8, U5.32 (PB12)
/PF3_TDI: C53.1, R48.1, U5.4 (PF3)
/PTT: C26.1, J1.11, U5.33 (PB13)
/RESET: J7.10 (~RESET), U5.12 (RESETn)
/RFP_RX: J4.1 (In), R74.2, TP5.1
/RFSW_RX: C74.1, U7.1 (J2)
/RFSW_TRX: C82.2, U7.5 (J1)
/RFSW_TX: C79.1, U7.3 (J3)
/RFVDD: C39.1, C40.1, R33.2, U5.9 (RFVDD)
/RF_2G4: J3.1 (In), NT71.1, U5.20 (2G4RF_IOP)
/RF_ANT: J5.1 (In), R78.1, R79.2
/RF_RX: C74.2, R72.1, R73.1
/RX_EN: J2.17, R76.1, U5.24 (PD15)
/RX_EN_SW: C81.1, R76.2, U7.4 (V2)
/SPK+: C25.1, FB11.2, J1.13
/SPK-: C24.1, FB12.2, J1.14
/SPK_DAC: R14.1, U5.23 (PD14)
/SPK_SDN: R15.1, U5.5 (PF4)
/SWCLK_TCK: J7.4 (SWCLK/TCK), U5.1 (PF0)
/SWDIO_TMS: J7.2 (SWDIO/TMS), U5.2 (PF1)
/SWO_TDO: J7.6 (SWO/TDO), U5.3 (PF2)
/TCXOVDD: C41.1, C42.1, R34.2, U6.4 (V+)
/TCXOout: R35.1, U6.3 (OUT)
/TX_EN: J2.19, R77.1, U5.22 (PD13)
/TX_EN_SW: C80.1, R77.2, U7.6 (V1)
/VBAT: C4.1, J1.16, J2.1, J2.2, R5.1, R11.2, R20.1
/VBAT1: C3.1, D1.1 (K), F1.2, J1.15, R3.1, U1.3 (BAT)
/VBAT_ADC: C11.1, Q4.2 (S), R12.1, R13.2
/VDD: C6.1, C7.1, FB31.1, FB32.1, J2.3, J7.1 (VTref), Q5.2 (S), R31.1, R32.1, R38.2, R40.1, U3.2 (VO)
/VDDS: C47.1, C52.1, J2.5, J9.1, Q4.1 (G), Q5.3 (D), R34.1, R39.2, R43.1
/VOL_In: C14.1, C15.1, J1.6
/VOL_Out: C13.2, J1.5, R24.2
/VREG_IN: C5.1, R5.2, U3.3 (VI)
/~CHRG: R1.2, U1.1 (~CHRG)
/~VDDS_EN: Q5.1 (G), R38.1, U5.48 (PC11)
unnamed: C12.1, C13.1, R14.2
unnamed: C15.2, R18.1
unnamed: C23.2, R23.2
unnamed: C72.1, T1.3, TP3.1
unnamed: C72.2, L71.2, L73.1
unnamed: C73.1, T2.2, TP4.1
unnamed: C73.2, L72.2, L73.2
unnamed: C76.1, L74.1, T3.4, T4.3
unnamed: C76.2, L75.1, T3.2, T4.2
unnamed: C78.2, T4.4
unnamed: C79.2, T4.1
unnamed: C84.1, L76.2, L77.1
unnamed: C84.2, NT72.1
unnamed: J7.8 (NC/TDI), R48.2
unnamed: J10.1, R44.1
unnamed: J10.2, R45.1
unnamed: J10.3, R46.1
unnamed: J10.4, R47.1
unnamed: Q4.3 (D), R11.1
unnamed: R71.1, T1.2, T2.3
unnamed: R72.2, T1.1
unnamed: R73.2, T2.1
unnamed: R36.1, U6.1 (EN)

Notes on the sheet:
Voltage regulator
SWD programming connector
Battery protection circuit
Header for battery and user interface
Input polarity protection
11 mm in between
Tooling holes
AMP_SDN is pulled up to voltage higher than EFR32 supply but it is connected to a 5 V tolerant pin so I think it should work by using the pin as an open drain output with over-voltage tolerance enabled.
DC blocking capacitors here may not be strictly necessary since the DC level on the RX pins seems to be 0 V.
38.4 MHz TCXO
Battery charger
Battery
Display mounting holes
Volume potentiometer
Speaker amplifier
0.2 mm wide 6 mm stub
Power switch
Connection to a display similar to this: https://www.ebay.com/itm/403774302965
Clock output option
Microphone input circuit
Chassis mounting holes
2.4 GHz match to the recommended 23+j11.5 ohm: 7.0 mm long 0.2 mm wide trace. 4.2 mm long 1.0 mm wide open stub spaced 0.2 mm from ground plane. The open stub also shorts 3rd harmonic.
Voltage divider for battery voltage measurement. Turned off in sleep mode.
Extra header for mounting display
18 mm (quarter wave) shorted stub to short even harmonics
Power switch to turn display and TCXO off in sleep mode
Power switch for display backlight
Expansion header. Can be used for an external PA or filter board. PA2 and PA5 are used for VBAT measurement and charge detection by default, but could be used for other purposes by removing some components from the board.

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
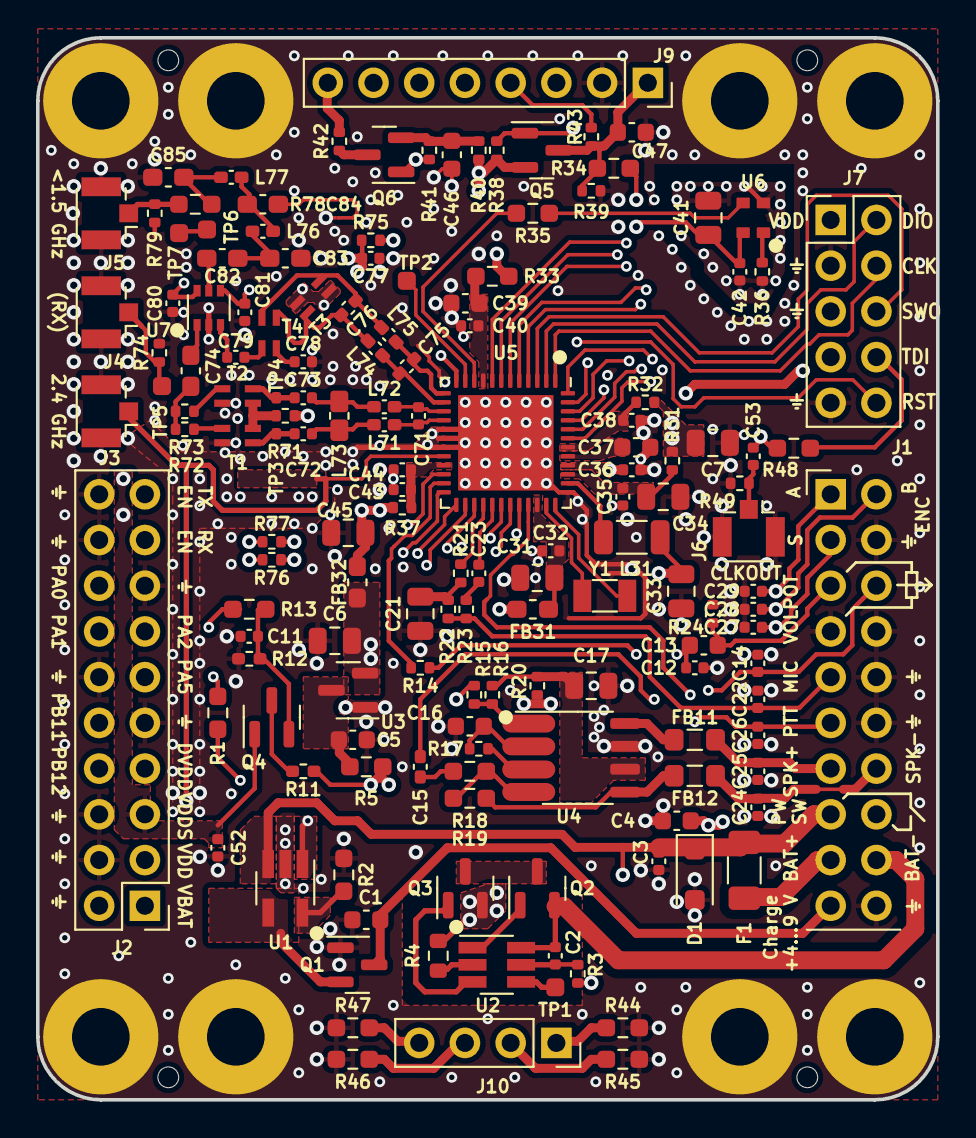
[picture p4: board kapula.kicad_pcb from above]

Board: 4 copper layers, 50.0 x 59.0 mm, 166 parts (0 on the bottom side), 119 nets.

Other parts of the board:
Q6: BSS84; SOT-23

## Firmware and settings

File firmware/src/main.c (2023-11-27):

/* SPDX-License-Identifier: MIT */

// emlib
#include "em_chip.h"
#include "em_cmu.h"
#include "em_emu.h"
#include "em_usart.h"
#include "em_gpio.h"
#include "em_timer.h"
#include "em_wdog.h"
#include "em_ldma.h"

#include "InitDevice.h"

#include <stdint.h>
#include <stdio.h>

// FreeRTOS
#include "FreeRTOS.h"
#include "task.h"
#include "semphr.h"

// rig
#include "display.h"
#include "ui.h"
#include "rig.h"
#include "dsp_driver.h"
#include "power.h"
#include "railtask.h"

/* --------------------
 * Interrupt priorities
 * --------------------
 * When changing these, remember to check
 * configLIBRARY_MAX_SYSCALL_INTERRUPT_PRIORITY in FreeRTOSConfig.h
 */

#define IRQPRI_RAIL 3
#define IRQPRI_SAMPLE_RATE_TIMER 3


/* ---------------------------------
 * Variables and function prototypes
 * ---------------------------------
 */

#define NTASKS 5
TaskHandle_t taskhandles[NTASKS];

void slow_dsp_task(void *);
void misc_fast_task(void *);

void debug_init(void);
void slow_dsp_rtos_init(void);

/* -------------
 * Main function
 * -------------
 * Initializes some hardware and tasks
 * before starting the RTOS scheduler.
 */
int main(void) {
	CHIP_Init();
	debug_init();
	printf("Gekkokapula\n");

	maybe_sleep();
	// If maybe_sleep returned, the device should turn on.
	// Crystal oscillator needs to be powered on before configuring clocks.
	// It's behind the same load switch as the display, so turn them on.
	GPIO_PinModeSet(TFT_EN_PORT, TFT_EN_PIN, gpioModePushPull, 0);

	enter_DefaultMode_from_RESET();
	CoreDebug->DEMCR |= CoreDebug_DEMCR_TRCENA_Msk;
	DWT->CTRL |= DWT_CTRL_CYCCNTENA_Msk;

	NVIC_SetPriorityGrouping(0);
	NVIC_SetPriority( FRC_PRI_IRQn, IRQPRI_RAIL);
	NVIC_SetPriority(     FRC_IRQn, IRQPRI_RAIL);
	NVIC_SetPriority(   MODEM_IRQn, IRQPRI_RAIL);
	NVIC_SetPriority( RAC_SEQ_IRQn, IRQPRI_RAIL);
	NVIC_SetPriority( RAC_RSM_IRQn, IRQPRI_RAIL);
	NVIC_SetPriority(    BUFC_IRQn, IRQPRI_RAIL);
	NVIC_SetPriority(     AGC_IRQn, IRQPRI_RAIL);
	NVIC_SetPriority(PROTIMER_IRQn, IRQPRI_RAIL);
	NVIC_SetPriority(   SYNTH_IRQn, IRQPRI_RAIL);
	NVIC_SetPriority( RFSENSE_IRQn, IRQPRI_RAIL);
	NVIC_SetPriority( WTIMER0_IRQn, IRQPRI_SAMPLE_RATE_TIMER);
	{
		LDMA_Init_t init = LDMA_INIT_DEFAULT;
		LDMA_Init(&init);
	}

	TIMER_TopSet(TIMER0, 199);
	TIMER_CompareBufSet(TIMER0, 0, 33);
	TIMER_CompareBufSet(TIMER0, 1, 20);
	dsp_hw_init();
	printf("Peripherals initialized\n");

	dsp_rtos_init();
	slow_dsp_rtos_init();
	ui_rtos_init();
	railtask_rtos_init();

	xTaskCreate(misc_fast_task, "Misc", 0x100, NULL, 4, &taskhandles[3]);
	xTaskCreate(display_task, "Display", 0x300, NULL, 2, &taskhandles[0]);
	xTaskCreate(railtask_main, "RAIL", 0x300, NULL, 2, &taskhandles[1]);
	xTaskCreate(fast_dsp_task, "Fast DSP", 0x300, NULL, 4, &taskhandles[4]);
	xTaskCreate(slow_dsp_task, "Slow DSP", 0x300, NULL, 2, &taskhandles[2]);

	printf("Starting scheduler\n");
	vTaskStartScheduler();
	return 0;
}


/* ---------------------
 * Some application code
 * ---------------------
 */

/* Task to do various "small" things which have to run regularly,
 * don't take much CPU time and don't need a dedicated task.
 * These are typically things that poll for something.
 * This includes:
 * - Reading user interface inputs
 * - Controlling display backlight brightness
 * - Monitoring other tasks
 */
void misc_fast_task(void *arg) {
	(void)arg;
	for(;;) {
		ui_check_buttons();
		ui_control_backlight();
		int ti;
		for(ti=0; ti<NTASKS; ti++) {
#if 0
			int v;
			v = uxTaskGetStackHighWaterMark(taskhandles[ti]);
			printf("%d:%4d | ", ti, v);
			if(ti == NTASKS-1) printf("\n");
#endif
		}
		vTaskDelay(10);
	}
}


/* --------------------------------------
 * RTOS hook functions and related things
 * --------------------------------------
 */

const char *current_task_name(void)
{
	TaskHandle_t t = xTaskGetCurrentTaskHandle();
	if (t != NULL)
		return pcTaskGetTaskName(t);
	else
		return "none";
}


void vApplicationStackOverflowHook()
{
	printf(":( Stack overflow in task %s\n", current_task_name());
	// beep
	uint32_t piip=0;
	for(;;) {
		TIMER_TopBufSet(TIMER0, 200);
		TIMER_CompareBufSet(TIMER0, 0, (((++piip)>>7)&63)+68);
	}
}


void vApplicationMallocFailedHook()
{
	printf(":( Malloc failed in task %s\n", current_task_name());
	// beep
	uint32_t piip=0;
	for(;;) {
		TIMER_TopBufSet(TIMER0, 200);
		TIMER_CompareBufSet(TIMER0, 0, (((++piip)>>8)&63)+68);
	}
}


void vApplicationIdleHook()
{
	__DSB();
	__WFI();
	__ISB();
}


void Default_Handler()
{
	/* Find the number of the current interrupt */
	printf(":( IRQ %d in task %s\n",
		(int)(SCB->ICSR & SCB_ICSR_VECTACTIVE_Msk) - 16,
		current_task_name());
	for (;;);
}

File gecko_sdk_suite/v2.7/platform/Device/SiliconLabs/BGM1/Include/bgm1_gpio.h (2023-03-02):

/***************************************************************************//**
 * @file
 * @brief BGM1_GPIO register and bit field definitions
 *******************************************************************************
 * # License
 * <b>Copyright 2020 Silicon Laboratories Inc. www.silabs.com</b>
 *******************************************************************************
 *
 * SPDX-License-Identifier: Zlib
 *
 * The licensor of this software is Silicon Laboratories Inc.
 *
 * This software is provided 'as-is', without any express or implied
 * warranty. In no event will the authors be held liable for any damages
 * arising from the use of this software.
 *
 * Permission is granted to anyone to use this software for any purpose,
 * including commercial applications, and to alter it and redistribute it
 * freely, subject to the following restrictions:
 *
 * 1. The origin of this software must not be misrepresented; you must not
 *    claim that you wrote the original software. If you use this software
 *    in a product, an acknowledgment in the product documentation would be
 *    appreciated but is not required.
 * 2. Altered source versions must be plainly marked as such, and must not be
 *    misrepresented as being the original software.
 * 3. This notice may not be removed or altered from any source distribution.
 *
 ******************************************************************************/

#if defined(__ICCARM__)
#pragma system_include       /* Treat file as system include file. */
#elif defined(__ARMCC_VERSION) && (__ARMCC_VERSION >= 6010050)
#pragma clang system_header  /* Treat file as system include file. */
#endif

/***************************************************************************//**
 * @addtogroup Parts
 * @{
 ******************************************************************************/
/***************************************************************************//**
 * @defgroup BGM1_GPIO GPIO
 * @{
 * @brief BGM1_GPIO Register Declaration
 ******************************************************************************/
/** GPIO Register Declaration */
typedef struct {
  GPIO_P_TypeDef P[6U];           /**< Port configuration bits */

  uint32_t       RESERVED0[184U]; /**< Reserved for future use **/
  __IOM uint32_t EXTIPSELL;       /**< External Interrupt Port Select Low Register  */
  __IOM uint32_t EXTIPSELH;       /**< External Interrupt Port Select High Register  */
  __IOM uint32_t EXTIPINSELL;     /**< External Interrupt Pin Select Low Register  */
  __IOM uint32_t EXTIPINSELH;     /**< External Interrupt Pin Select High Register  */
  __IOM uint32_t EXTIRISE;        /**< External Interrupt Rising Edge Trigger Register  */
  __IOM uint32_t EXTIFALL;        /**< External Interrupt Falling Edge Trigger Register  */
  __IOM uint32_t EXTILEVEL;       /**< External Interrupt Level Register  */
  __IM uint32_t  IF;              /**< Interrupt Flag Register  */
  __IOM uint32_t IFS;             /**< Interrupt Flag Set Register  */
  __IOM uint32_t IFC;             /**< Interrupt Flag Clear Register  */
  __IOM uint32_t IEN;             /**< Interrupt Enable Register  */
  __IOM uint32_t EM4WUEN;         /**< EM4 Wake Up Enable Register  */

  uint32_t       RESERVED1[4U];   /**< Reserved for future use **/
  __IOM uint32_t ROUTEPEN;        /**< I/O Routing Pin Enable Register  */
  __IOM uint32_t ROUTELOC0;       /**< I/O Routing Location Register  */

  uint32_t       RESERVED2[2U];   /**< Reserved for future use **/
  __IOM uint32_t INSENSE;         /**< Input Sense Register  */
  __IOM uint32_t LOCK;            /**< Configuration Lock Register  */
} GPIO_TypeDef;                   /** @} */

/***************************************************************************//**
 * @addtogroup BGM1_GPIO
 * @{
 * @defgroup BGM1_GPIO_BitFields  GPIO Bit Fields
 * @{
 ******************************************************************************/
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

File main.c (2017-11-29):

/***************************************************************************//**
 * @file main.c
 * @brief Simple RAIL application which includes hal
 * @copyright Copyright 2017 Silicon Laboratories, Inc. http://www.silabs.com
 ******************************************************************************/
#include "rail.h"
#include "hal_common.h"
#include "rail_config.h"
#include "pa.h"

#include "em_chip.h"
#include "em_usart.h"
#include "em_gpio.h"
#include "em_timer.h"

#include "InitDevice.h"

#include <stdint.h>
#include "arm_math.h"
#include "arm_const_structs.h"

uint8_t nollaa[300] = {255,255,0};

// parameters
struct {
	int channel;
	int channel_changed;
	enum { MODE_FM, MODE_DSB } mode;
} p = {0,0,1};

void startrx() {
	RAIL_RfIdleExt(RAIL_IDLE, true);
	RAIL_ResetFifo(false, true);
	RAIL_SetRxFifoThreshold(100); //FIFO size is 512B
	RAIL_EnableRxFifoThreshold();
	RAIL_RxStart(p.channel);
}

void starttx() {
	RAIL_RfIdleExt(RAIL_IDLE_ABORT, true);
	RAIL_ResetFifo(true, false);
	RAIL_SetTxFifoThreshold(100);
	RAIL_WriteTxFifo(nollaa, 300);
	RAIL_TxStart(p.channel, NULL, NULL);
}

void transmit_something() {
	RAIL_TxData_t txstuff = { nollaa, 200 };
	RAIL_RfIdleExt(RAIL_IDLE_ABORT, true);
	RAIL_ResetFifo(true, false);
	RAIL_TxDataLoad(&txstuff);
	RAIL_TxStart(p.channel, NULL, NULL);
}

void initRadio() {
  RAIL_Init_t railInitParams = {
    256,
    RADIO_CONFIG_XTAL_FREQUENCY,
    RAIL_CAL_ALL,
  };
  RADIO_PA_Init(&(RADIO_PAInit_t){
	    PA_SEL_2P4_HP,    /* Power Amplifier mode */
	    PA_VOLTMODE_VBAT, /* Power Amplifier vPA Voltage mode */
	    190,              /* Desired output power in dBm * 10 */
	    0,                /* Output power offset in dBm * 10 */
	    10,               /* Desired ramp time in us */
  });

  //halInit();
  RAIL_RfInit(&railInitParams);
  USART_Tx(USART0, '1');
  RAIL_RfIdleExt(RAIL_IDLE, true);
  USART_Tx(USART0, '2');

  RAIL_CalInit_t calInit = {
    RAIL_CAL_ALL,
    irCalConfig,
  };
  RAIL_CalInit(&calInit);
  USART_Tx(USART0, '3');

  RAIL_PacketLengthConfigFrameType(frameTypeConfigList[0]);
  USART_Tx(USART0, '4');
  if (RAIL_RadioConfig((void*)configList[0])) {
    //while (1) ;
	  USART_Tx(USART0, 'f');
  }
  USART_Tx(USART0, '5');

  RAIL_ChannelConfig(channelConfigs[0]);
  USART_Tx(USART0, '6');

  RAIL_DataConfig_t dataConfig = { TX_PACKET_DATA, RX_IQDATA_FILTLSB, FIFO_MODE /*PACKET_MODE*/, FIFO_MODE };
  RAIL_DataConfig(&dataConfig);
  USART_Tx(USART0, '7');
}

static inline void read_encoder() {
	const int enc_map[4] = { 0, 1, 3, 2 };
	int enc, enc_diff, channel;
	static int enc_prev=0;
	enc = enc_map[
			GPIO_PinInGet(ENC1_PORT, ENC1_PIN) + 2*
			GPIO_PinInGet(ENC2_PORT, ENC2_PIN)];
	enc_diff = (enc - enc_prev) & 3;
	channel = p.channel;
	if(enc_diff == 1) channel++;
	if(enc_diff == 3) channel--;
	if(channel != p.channel) {
		p.channel = channel;
		p.channel_changed = 1;
	}
	enc_prev = enc;
}

#define FFTLEN 128
const arm_cfft_instance_f32 *fftS = &arm_cfft_sR_f32_len128;
float fftbuf[2*FFTLEN];
volatile int fftbufp = 0;

#define RXBUFL 2
typedef int16_t iqsample_t[2];
iqsample_t rxbuf[RXBUFL];
void RAILCb_RxFifoAlmostFull(uint16_t bytesAvailable) {
	unsigned nread, i;
	static int psi=0, psq=0;
	static int agc_level=0;
	GPIO_PortOutToggle(gpioPortF, 4);
	nread = RAIL_ReadRxFifo((uint8_t*)rxbuf, 4*RXBUFL);
	nread /= 4;
	int ssi=0, ssq=0, fm = 0;
	for(i=0; i<nread; i++) {
		int si=rxbuf[i][0], sq=rxbuf[i][1];
		int fi, fq;
		switch(p.mode) {
		case MODE_FM:
			// multiply by conjugate
			fi = si * psi + sq * psq;
			fq = sq * psi - si * psq;
			/* Scale maximum absolute value to 0x7FFF.
			 * This can be done because FM demod doesn't care about amplitude.
			 */
			while(fi > 0x7FFF || fi < -0x7FFF || fq > 0x7FFF || fq < -0x7FFF) {
				fi /= 0x100; fq /= 0x100;
			}
			// very crude approximation...
			fm += 0x8000 * fq / ((fi>=0?fi:-fi) + (fq>=0?fq:-fq));
			break;
		case MODE_DSB: {
			int agc_1, agc_diff;
			static int audio_lpf = 0;
			audio_lpf += (si*128 - audio_lpf)/16;
			fi = audio_lpf/128; // TODO: SSB filter

			// AGC
			agc_1 = (fi>=0?fi:-fi) * 0x100; // rectify
			agc_diff = agc_1 - agc_level;
			if(agc_diff > 0)
				agc_level += agc_diff/64;
			else
				agc_level += agc_diff/256;

			fm += 0x1000 * fi / (agc_level/0x100);

			} break;
		}

		psi = si; psq = sq;
		ssi += si; ssq += sq;
	}

	int fp = fftbufp;
	if(fp < 2*FFTLEN) {
		const float scaling = 1.0f / (RXBUFL*0x8000);
		fftbuf[fp]   = scaling*ssi;
		fftbuf[fp+1] = scaling*ssq;
		fftbufp = fp+2;
	}

	fm = (fm / 0x100) + 100;
	if(fm < 0) fm = 0;
	if(fm > 200) fm = 200;
	TIMER_CompareBufSet(TIMER0, 0, fm);
	//USART_Tx(USART0, 'r');

	read_encoder();
}

void RAILCb_TxFifoAlmostEmpty(uint16_t bytes) {
	GPIO_PortOutToggle(gpioPortF, 4);
	RAIL_WriteTxFifo(nollaa, 100);
	USART_Tx(USART0, 'e');
}

void display_loop();
void display_fft_line(float *data);


int main(void) {
	enter_DefaultMode_from_RESET();
	USART_Tx(USART0, 'a');
	initRadio();
 	USART_Tx(USART0, 'b');

 	TIMER_TopSet(TIMER0, 200);
 	TIMER_CompareBufSet(TIMER0, 0, 33);

	for(;;) {
		unsigned keyed = !GPIO_PinInGet(PTT_PORT, PTT_PIN);
		if(keyed && (RAIL_RfStateGet() != RAIL_RF_STATE_TX || p.channel_changed)) {
			p.channel_changed = 0;
			RAIL_RfIdleExt(RAIL_IDLE_ABORT, false);
			RAIL_TxToneStart(p.channel);
		}
		if((!keyed) && (RAIL_RfStateGet() != RAIL_RF_STATE_RX || p.channel_changed)) {
			p.channel_changed = 0;
			RAIL_TxToneStop();
			startrx();
		}

		if(fftbufp >= 2*FFTLEN) {
			arm_cfft_f32(fftS, fftbuf, 0, 1);
			display_fft_line(fftbuf);
			fftbufp = 0;
		}

		//USART_Tx(USART0, 'y');
		display_loop();
		GPIO_PortOutSet(gpioPortF, 5);
		GPIO_PortOutClear(gpioPortF, 5);
	}
	return 0;
}

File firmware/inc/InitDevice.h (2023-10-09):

/* SPDX-License-Identifier: MIT */

//=========================================================
// inc/InitDevice.h: generated by Hardware Configurator
//
// This file will be regenerated when saving a document.
// leave the sections inside the "$[...]" comment tags alone
// or they will be overwritten!
//=========================================================
#ifndef __INIT_DEVICE_H__
#define __INIT_DEVICE_H__

// USER CONSTANTS
// USER PROTOTYPES

// $[Mode Transition Prototypes]
extern void enter_DefaultMode_from_RESET(void);
// [Mode Transition Prototypes]$

// $[Config(Per-Module Mode)Transition Prototypes]
extern void EMU_enter_DefaultMode_from_RESET(void);
extern void LFXO_enter_DefaultMode_from_RESET(void);
extern void CMU_enter_DefaultMode_from_RESET(void);
extern void ADC0_enter_DefaultMode_from_RESET(void);
extern void ACMP0_enter_DefaultMode_from_RESET(void);
extern void ACMP1_enter_DefaultMode_from_RESET(void);
extern void IDAC0_enter_DefaultMode_from_RESET(void);
extern void RTCC_enter_DefaultMode_from_RESET(void);
extern void USART0_enter_DefaultMode_from_RESET(void);
extern void USART1_enter_DefaultMode_from_RESET(void);
extern void LEUART0_enter_DefaultMode_from_RESET(void);
extern void WDOG0_enter_DefaultMode_from_RESET(void);
extern void I2C0_enter_DefaultMode_from_RESET(void);
extern void GPCRC_enter_DefaultMode_from_RESET(void);
extern void LDMA_enter_DefaultMode_from_RESET(void);
extern void TIMER0_enter_DefaultMode_from_RESET(void);
extern void TIMER1_enter_DefaultMode_from_RESET(void);
extern void LETIMER0_enter_DefaultMode_from_RESET(void);
extern void CRYOTIMER_enter_DefaultMode_from_RESET(void);
extern void PCNT0_enter_DefaultMode_from_RESET(void);
extern void PRS_enter_DefaultMode_from_RESET(void);
extern void PORTIO_enter_DefaultMode_from_RESET(void);
// [Config(Per-Module Mode)Transition Prototypes]$

// $[User-defined pin name abstraction]

#if KAPULA_v1
	#define ENC1_PIN            (11)
	#define ENC1_PORT           (gpioPortD)
	#define ENC1_TIM1_CC0       TIMER_ROUTELOC0_CC0LOC_LOC19

	#define ENC2_PIN            (12)
	#define ENC2_PORT           (gpioPortD)
	#define ENC2_TIM1_CC1       TIMER_ROUTELOC0_CC1LOC_LOC19

	#define ENCP_PIN            (13)
	#define ENCP_PORT           (gpioPortD)

	#define PTT_PIN             (6)
	#define PTT_PORT            (gpioPortF)

	#define BACKLIGHT_PIN_INVERTED 0

	#define PWM_PIN             (10)
	#define PWM_PORT            (gpioPortD)
	#define PWM_TIM0_CC0        TIMER_ROUTELOC0_CC0LOC_LOC18

	#define MIC_APORT           adcPosSelAPORT4XCH7 // PD15

#elif KAPULA_v2
	#define ENC1_PIN            (5)
	#define ENC1_PORT           (gpioPortF)
	#define ENC1_TIM1_CC0       TIMER_ROUTELOC0_CC0LOC_LOC29

	#define ENC2_PIN            (6)
	#define ENC2_PORT           (gpioPortF)
	#define ENC2_TIM1_CC1       TIMER_ROUTELOC0_CC1LOC_LOC29

	#define ENCP_PIN            (7)
	#define ENCP_PORT           (gpioPortF)

	#define PTT_PIN             (13)
	#define PTT_PORT            (gpioPortB)

	#define BACKLIGHT_PIN_INVERTED 1

	#define PWM_PIN             (14)
	#define PWM_PORT            (gpioPortB)
	#define PWM_TIM0_CC0        TIMER_ROUTELOC0_CC0LOC_LOC9

	#define USE_OPAMPS
	#define MIC_APORT           adcPosSelDAC0OUT0
//	#define MIC_APORT           adcPosSelAPORT3XCH10 // PA2
//	#define MIC_APORT           adcPosSelAPORT1YCH19 // PF3
//	#define MIC_APORT           adcPosSelAPORT2YCH18 // PF2

	#define MIC_EN_PIN          (3)
	#define MIC_EN_PORT         (gpioPortA)

	#define SPK_EN_PIN          (4)
	#define SPK_EN_PORT         (gpioPortF)

	#define RX_EN_PIN           (15)
	#define RX_EN_PORT          (gpioPortD)

	#define TX_EN_PIN           (13)
	#define TX_EN_PORT          (gpioPortD)

#else
	#error "Unsupported or missing KAPULA_model"
#endif



#define TFT_CS_PIN          (7)
#define TFT_CS_PORT         (gpioPortC)

#define TFT_DC_PIN          (9)
#define TFT_DC_PORT         (gpioPortC)

#define TFT_LED_PIN         (10)
#define TFT_LED_PORT        (gpioPortC)

#define TFT_EN_PIN          (11)
#define TFT_EN_PORT         (gpioPortC)

#define TEST_PIN          (11)
#define TEST_PORT         (gpioPortB)

// [User-defined pin name abstraction]$

#endif

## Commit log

2017-09-22 Generated code. It compiles
    [efr32_radio_configurator_log.txt]
2017-09-24 Trying to control display (not working)
    [InitDevice.h, display.c, main.c]
2017-11-26 Trying to make it transmit (without success yet) + some display experiments
    [efr32_radio_configurator_log.txt]
2017-11-26 TX works now: RADIO_PA_Init was missing
    [main.c]
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2017-11-26 Spectrogram display works now
    There was a buffer overflow bug in reading RX fifo
    because of fixed buffer size forgotten as a parameter.
    arm_cfft_f32 also needed bitReverseFlag=1
    for non-bit-reversed ordering of output.
    [display.c, main.c]
2017-11-29 Add crude DSB demodulation and encoder for channel selection
2017-11-30 Some UI improvements
    Also put RAIL idle before changing frequency to avoid crash
    [display.c, main.c, ui.c]
2017-12-03 Use quadrature decoder in timer peripheral, refactored UI code to use it
2017-12-03 Add mode settings and signal meter in UI
    Also tried to enable watchdog but the program stopped working completely
    so it seems to reset the CPU before peripheral init is done.
    Watchdog code is there but its initialization is commented out for now.
    [main.c, ui.c]
2017-12-03 Use DMA for SPI, UI improvements
    Also enabled ADC peripheral which is going to be used
2017-12-03 ADC test: print value on display
    Also removed watchdog because its initialization got stuck
    waiting for WDOG_SYNCBUSY_CTRL to clear.
    [main.c, ui.c]
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2018-01-08 Test modulation by RAIL frequency override, UI fixes
    [main.c, ui.c]
2018-01-11 Updated RAIL version
    [efr32_radio_configurator_log.txt]
2018-03-25 Fix priorities to let RAIL task run
    [main.c]
2018-03-25 Update RAIL version to 2.12.8
    [efr32_radio_configurator_log.txt]
2018-03-25 Making more use of FreeRTOS
    DMA interrupt can now notify a task waiting for it,
    allowing other tasks to run in between.
    To help choose task sizes, stack watermarks are printed to debug UART.
2018-03-26 Small UI changes. Restart stuck RAIL task.
    [display.c, main.c, ui.c]
2018-03-31 More RAIL hacking
    Removing asserts extends the tuning range a bit.
    Now it, however, seems to reset the whole CPU when tuning way too low.
2018-03-31 Waterfall averaging and some optimization
    It does not look very smooth yet. Looks like DSP interrupt is already
    taking a bit too much CPU because setting demodulation to none
    makes the waterfall go much faster.
    [ui.c]
2020-03-20 Move code under firmware/
    [efr32_radio_configurator_log.txt]
2020-03-20 Draft a partial schematic for Gekko2
    [kapula.kicad_pcb, kapula.sch]
2020-03-20 Add Makefile
    The code should be ported to use RAIL 2,
    but for now calls to RAIL are commented out.
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2020-03-21 Start porting to RAIL 2
    Now it compiles, doesn't seem to work yet but doesn't crash either.
2020-03-21 RAIL 2 port: RX and TX working
    Frequency cannot be changed yet
2020-03-24 Start implementing SSB
    Unfinished. I have to get more familiar with biquad filters.
2020-03-24 Fix biquad filter
    Now it does SSB
2020-03-25 Add a separate RAIL configurator project
    [efr32_radio_configurator_log.txt]
2020-05-24 PCB: Add some components and footprints
    [kapula.kicad_pcb, kapula.sch]
2020-05-25 PCB: Add some part numbers and circuit details
    [kapula.kicad_pcb, kapula.sch]
2020-05-25 PCB: Attempt some layout for RF parts
    [kapula.kicad_pcb, kapula.sch]
2020-05-26 PCB dimensions and more part numbers
    [kapula.kicad_pcb, kapula.sch]
2020-05-26 PCB: Place components approximately in layout
    [kapula.kicad_pcb, kapula.sch]
2020-05-26 PCB: Most of RF layout routed
    [kapula.kicad_pcb, kapula.sch]
2020-05-27 PCB: Add some connectors and more routing
    [kapula.kicad_pcb, kapula.sch]
2020-05-27 PCB: Route display and knob traces
    [kapula.kicad_pcb, kapula.sch]
2020-05-27 PCB: More layout
    [kapula.kicad_pcb, kapula.sch]
2020-05-27 PCB: Everything routed
    [kapula.kicad_pcb, kapula.sch]
2020-05-27 PCB: Silkscreen markings and other small tweaks
    [kapula.kicad_pcb]
2020-05-27 PCB: More clear BOM, some changes
    [kapula.kicad_pcb, kapula.sch]
2020-06-30 Fix pinout bugs. Add radio configuration for v2 model.
    [efr32_radio_configurator_log.txt]
2020-09-23 Fix v2 RAIL version and a small UI bug
    [ui.c]
2020-09-30 Test sub-GHz on v2
    It's fixed on sub-GHz now, so this version doesn't work on 2.4 GHz.
    [efr32_radio_configurator_log.txt]
2022-08-07 Fix default frequency for 2.4 GHz single band models
    [ui.c]
2022-08-07 Fix pinout bugs for v1 model
    [InitDevice.h]
2022-08-12 Test changing intermediate frequency
    This commit shows how the intermediate frequency (IF)
    parameter affects the values in the RAIL configuration table.
    I found the old Simplicity Studio installation
    that was used to generate the previous configuration.
    I verified it still generated exactly
    the same RAIL configuration values.
    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
    [efr32_radio_configurator_log.txt]
2022-08-12 Test changing designed RF frequency
    This is similar to the previous commit but this time changing
    the base frequency the RAIL configuration is generated for.
2022-08-12 Fix frequencies for v1
    [efr32_radio_configurator_log.txt]
2022-08-13 Add power off mode
    Hardware was also modified a bit.
    TCXO is now powered through the same load switch as the display.
    This simplifies both hardware and software by eliminating the need
    for a separate TCXO enable pin.
2023-03-02 Add OpenOCD scripts
    These were already written in Aug 14 2022
    but had not been committed yet.
    [rtt.cfg, v1_flash_rtt.cfg, v2_flash_rtt.cfg]
2023-03-16 Test using internal opamp as microphone amplifier
    Opamp output is now temporarily on PF3 and ADC input on PF2
    for testing purposes.
    Input is still on PA2 but R18 and Q4 should be removed
    from the old circuit to make the input AC coupled.
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2023-09-24 Merge PCB version 2.1
    Squashed commit of the following:
    commit 2dcb03bf70b156ae0bbcacb409ca34cc4d5f4f49
    Author: Tatu Peltola <tatu.peltola@gmail.com>
    Date: Sun Sep 24 18:44:38 2023 +0300
    PCB: Add information on stackup and assembly
    commit eb25dc4c16027e2ae7dc3ef2adc563e1bd2dee15
    Author: Tatu Peltola <tatu.peltola@gmail.com>
    Date: Sun Sep 17 21:56:33 2023 +0300
    PCB: Fix one more part number
    commit 406db7ab08140ab049fac52208bf08ade03df38b
    Author: Tatu Peltola <tatu.peltola@gmail.com>
    Date: Sun Sep 17 21:37:43 2023 +0300
    PCB: Fix some component values and part numbers for fabrication
    commit bd726e2c45a1992909abfc08a1a84df34a49772b
    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
    [kapula.kicad_pcb, kapula.kicad_sch, kapula.sch]
2023-09-24 Organize files, add hardware documentation
    [kapula.kicad_pcb, kapula.kicad_sch]
2023-09-26 Fix bug causing random frequency offset in RX
    Apparently RAIL did not always rewrite channel register of the
    synthesizer when starting RX after the register had been
    used to modulate TX. This is a quick fix to the problem.
    I actually fixed this in May 27th already but forgot to commit.
    [dsp_driver.c]
2023-09-26 Invert backlight control for hardware v2.1
    [InitDevice.h, display.c]
2023-09-26 Add wiring diagram to documentation
    [connections.kicad_pcb, connections.kicad_sch]
2023-09-27 Make wiring diagram more clear
    [connections.kicad_sch]
2023-09-28 Add support for different SWD adapters, document flashing better
    [adapter.cfg, rtt.cfg, v1_flash_rtt.cfg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]
2023-09-29 Improve sleep mode
    Now it does not go to sleep when powered on.
    Also change UI to need an extra button press
    to make it less easy to accidentally put it into sleep.
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2023-10-01 Prevent going to sleep from debugger reset
    [power.c]
2023-10-03 Document flashing better
    [adapter.cfg, flash_v1.cfg, flash_v2.cfg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]
2023-10-08 Add inputs to build task, improve documentation
    [flash_v1.cfg, flash_v2.cfg]
2023-10-09 Make naming of files and hardware versions more consistent
    [flash_v1.cfg, flash_v2.cfg]
2023-10-10 Move DSP driver buffers and indexes to one struct
    This did not seem to make a difference in performance,
    but maybe it will keep code a bit cleaner when more
    variables are added.
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2023-10-12 Fix microphone input configuration
    [dsp_driver.c]
2023-11-21 Fix split range so that it always fits in display
    [ui.c]
2023-11-22 Fix text maximum length
    [ui.c]
2023-11-24 Fix UI view for other modes
    [ui.c]
2023-11-26 Fix SSB transmit
    Seems like atan2f was working differently on real hardware
    than in the test program. I am not sure why.
    Now it is replaced with an approximation which is probably
    a good idea anyway.
    [dsp_math.h]
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2023-11-27 Fix TX sample rate
    [dsp_driver.c, main.c]
2024-02-11 Fix display initialization
    Send MADCTL command (Memory Data Access Control)
    to make sure display memory is in the correct order.
    This fixes a problem with some displays where the order seems
    to get a random value if it is not set.
    Also add a 120 ms delay suggested in ST7735 datasheet.
    [display.c]
2024-02-21 Merge PCB version 2.2
    commit 29585da15be33afe63cdd15af44b5699f67d3afb
    Date: Wed Feb 21 15:40:03 2024 +0200
    Update documentation for hardware v2.2
    commit 29c90c9b898eb7544d7174a70b0680bc57b382f8
    Date: Tue Feb 20 14:58:30 2024 +0200
    PCB: Rename net 1V8 to DVDD
    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
    [kapula.kicad_pcb, kapula.kicad_sch]
